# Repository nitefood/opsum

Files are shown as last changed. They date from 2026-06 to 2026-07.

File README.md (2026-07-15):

# OPSUM - The Open PSU Meter project

OPSUM is a **DC voltmeter and ammeter board** with 4mm banana socket inputs, that enables measuring and logging **voltage, current and power**, even when using a bench PSU that has no builtin telemetry feature. Communication between the board and the host happens via **UART protocol** over a dedicated USB port that is **galvanically isolated** from the PSU/DUT (*power supply unit and device under test*) side of the PCB, in order to protect the host-side (PC) from potentially destructive shorts or spikes happening on the DUT side.

This repository is structured as a **monorepo**: hardware design files, enclosure CAD files, firmware, host-side GUI tools, release binaries, communication protocol documentation, and third-party GUIs are kept together so you can build, flash, and evolve the project starting from a single source of truth.

## Features

#### Current

- **Real-time voltage, current, and power monitoring** based on the [INA226](https://www.ti.com/product/INA226) monitor IC and the [ESP32-S3](https://www.espressif.com/en/products/socs/esp32-s3) SoC.
- [Kelvin-sensed](https://en.wikipedia.org/wiki/Four-terminal_sensing) shunt layout and full noise filtering (as per TI's [datasheet](https://www.ti.com/lit/ds/symlink/ina226.pdf), chapter *6.4.2 "Filtering and Input Considerations"*) for improved measurement accuracy.
- **Reverse-polarity**, **overvoltage**, and **negative-voltage** protection circuitry.
- PMOS input protection stage with zener-clamped gate drive.
- TVS + Schottky protected INA VBUS input.
- **Galvanic isolation** protecting the host-side USB port from the PSU/DUT side.
- Handles up to **36 V** bus voltage and **20 A** current.
- Compact, low-cost, fully **open source hardware, firmware and software** project.

#### Planned

- I<sup>2</sup>C display showing real time telemetry from the board *(I<sup>2</sup>C pin header for the display is already present on the PCB, only needs designing the enclosure lid opening and in-firmware support)*

## Images
Enclosure render (outside) | Enclosure render (inside)
| - | - |
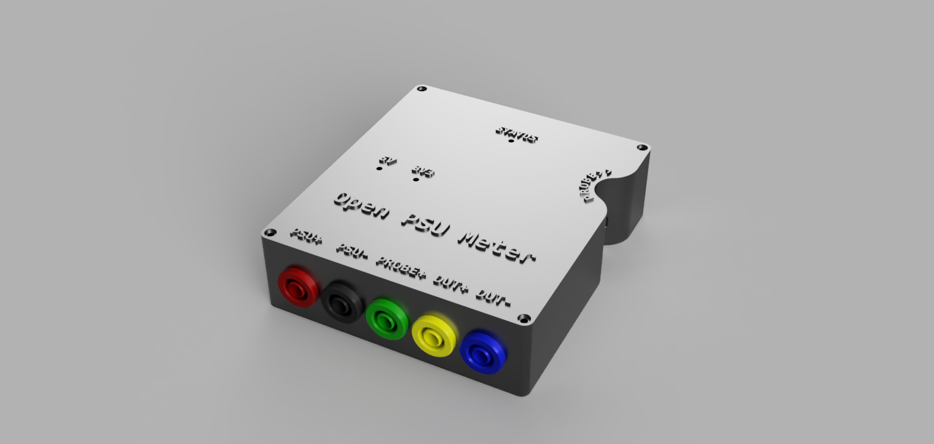
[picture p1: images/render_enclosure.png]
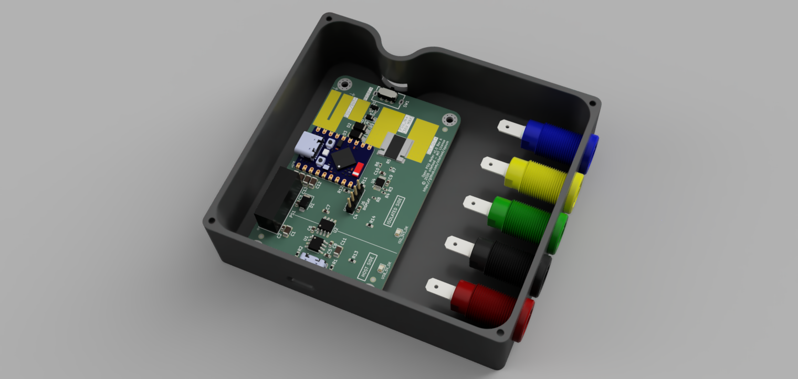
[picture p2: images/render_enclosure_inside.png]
|  |  |

PCB Layout | PCB 3D View
| - | - |
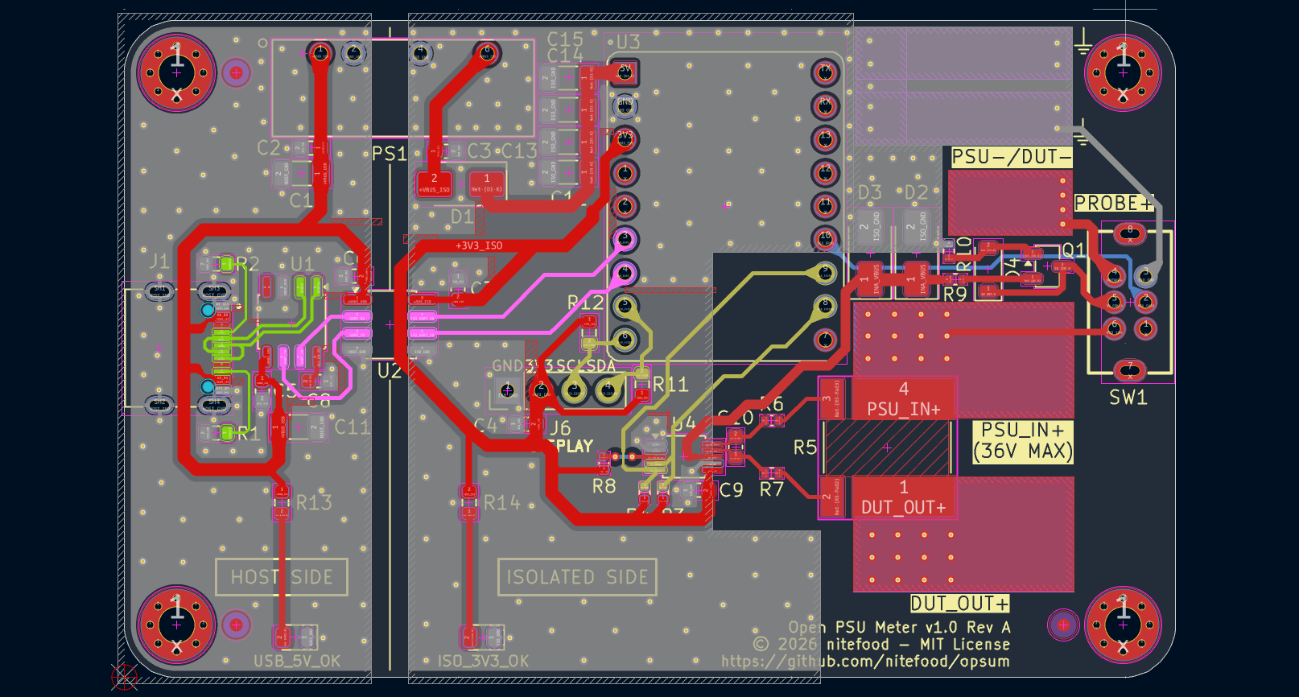
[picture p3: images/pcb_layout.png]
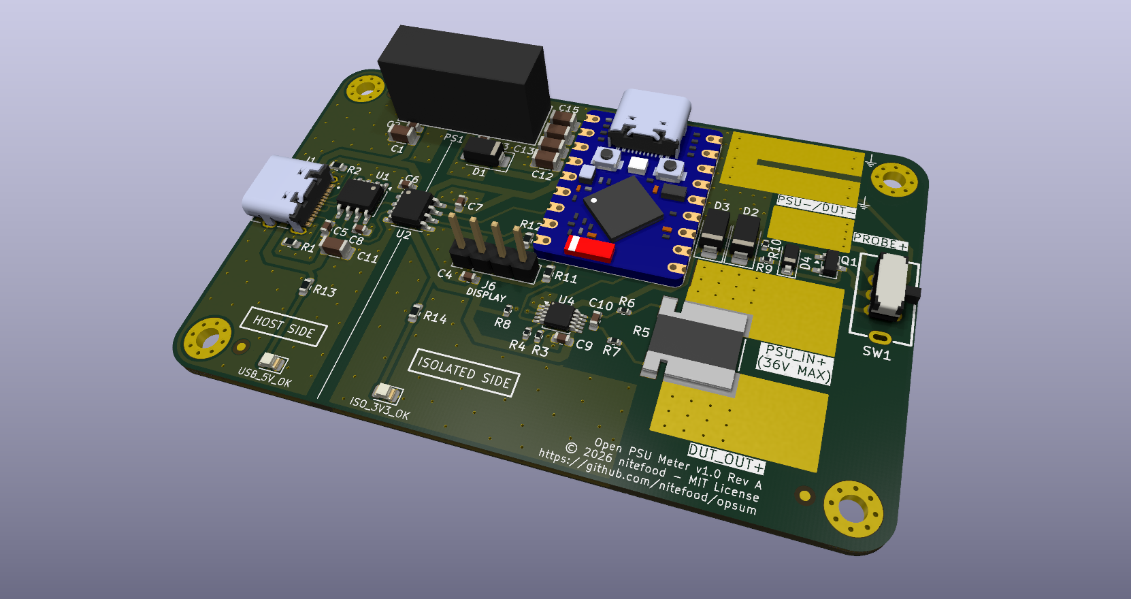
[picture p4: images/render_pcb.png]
 |  |

3D printed enclosure (top view) | 3D printed enclosure (sockets visible)
| - | - |
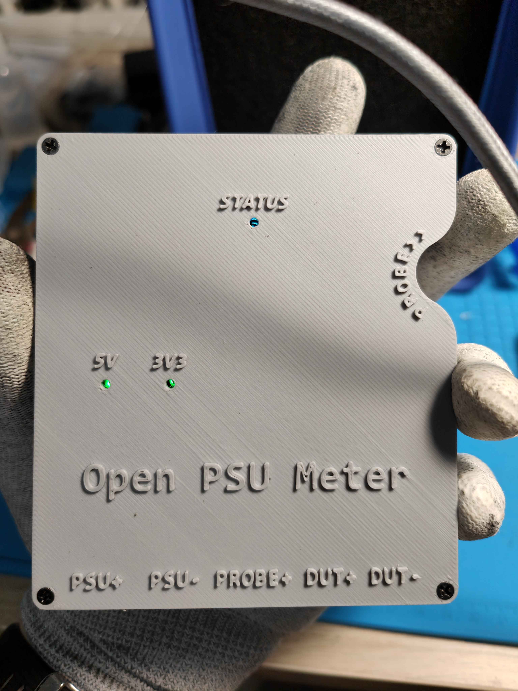
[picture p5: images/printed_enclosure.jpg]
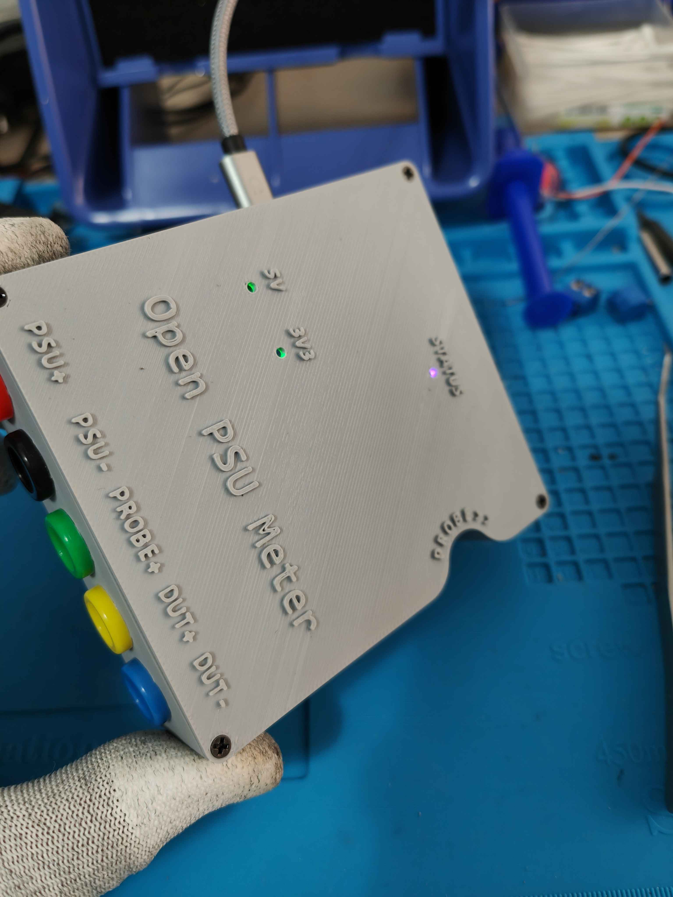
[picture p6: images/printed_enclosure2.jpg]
|  |  |

#### 3D printed enclosure (internal 12AWG wiring)
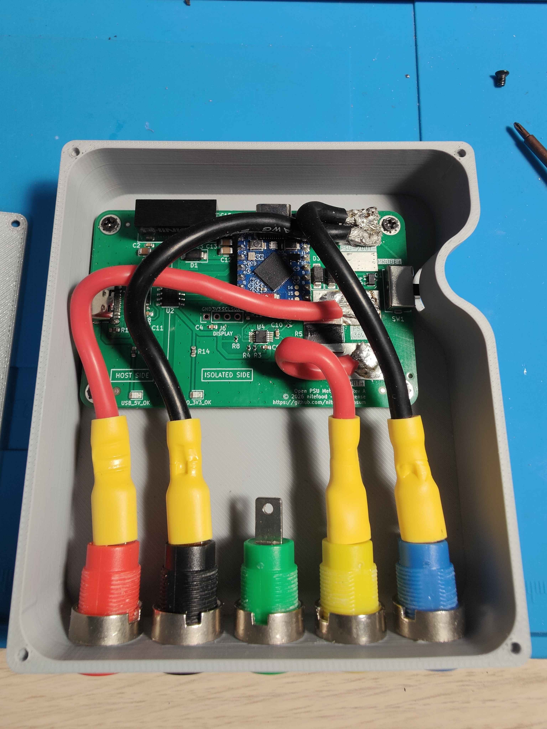
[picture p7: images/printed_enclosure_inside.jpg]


#### [Farmtech's PSU monitor](/third_party_tools/farmtech/) displaying telemetry coming from a live OPSUM board
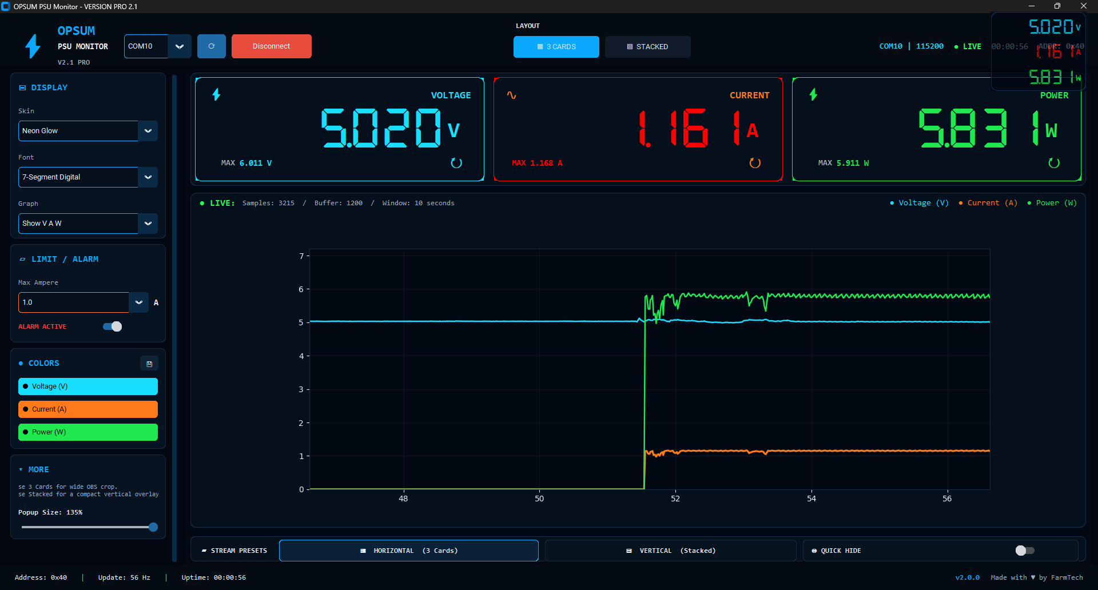
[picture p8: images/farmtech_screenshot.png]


---

## Quick Start

If you want to build the project yourself, the step-by-step approach is:

1. **Manufacture the board** using a third party PCB fab house (I've used [JLCPCB](https://jlcpcb.com/?from=DUYEWB) with great results, so tolerances and specs are guaranteed to comply with their capabilities, but any fab house should be easily capable to manufacture this board). **Gerbers, BOM and CPL** files alongside required production settings and instructions for PCB manufacturing and assembly are all in the [hardware](/hardware/) section.
	> Disclaimer: the JLCPCB link above is a referral URL, I get a little kickback if you use it to subscribe or buy from them. Thanks for your support!
2. **Solder the remaining through-hole components on the PCB** using the instruction under [howto-build](/howto-build/). I've included a bill of material for THT and hand-assembly components required to complete the project, complete with links to AliExpress to source them.
3. **First-flash the new ESP32-S3 board** with the `-FULL` image (using `esptool`). Prebuilt binaries and usage instructions for `esptool` are in the [dist](dist/) section.
4. **3D print the enclosure and assemble the finished product**. Instructions are under [enclosure](/enclosure/).
5. **Connect the USB port to your PC and use a client-side program** to interface with the OPSUM board and receve its readings. I've included a [minimal GUI](dist/opsum_gui.exe), alongside with fully featured [third party tools](third_party_tools/) compatibile with OPSUM's core firmware [protocol](./protocol-specs/core-uart.md).

If you want to flash a different firmware, or update/reflash the core firmware in the future, there is **no need to disassemble the board** to access the native MCU USB port. Just use the **isolated USB port** with the included [flash tool](dist/flashtool.exe), and reflash the board using a `-OTA` image. OPSUM's main firmware OTA image is packaged under [dist](dist/) as well.

## Open Tooling Approach

This repository includes everything, ranging from the basic OPSUM GUI plus third-party client-side tools that support the Core firmware communication protocol, to enclosure CAD models, PCB layout design files, assembly guides and protocol specification documentation.

You are free to use whichever compatible client (or firmware) matches your needs.

## Repository Layout

| Folder | Contents |
| - | - |
| [dist/](dist/) | release binaries + compilation and flash instructions |
| [protocol-specs/](protocol-specs/) | **DFU** (flashing) and **UART** (runtime communication with the host) protocol specs |
| [src/Firmware/](src/Firmware/) | **Core** (main) and **DFU** (flash update mode) firmware source code |
| [src/GUI/](src/GUI/) | host-side GUI tools source code root folder |
| [src/GUI/flash-tool/](src/GUI/flash-tool/) | desktop DFU flashing GUI source code |
| [src/GUI/opsum-gui/](src/GUI/opsum-gui/) | minimal OPSUM runtime GUI frontend source code |
| [third_party_tools/](third_party_tools/) | bundled alternative host-side tools and board-side firmware binaries |
| [hardware/](hardware/) | schematic, PCB layout, BOM, CPL, Gerbers and manufacturing guide |
| [enclosure/](enclosure/) | CAD files for the OPSUM case |
| [howto-build/](howto-build/) | Manual assembly and soldering step-by-step instructions for the OPSUM board project |

## Contributing

**OPSUM is inteded as an open, community driven project**. Anyone is welcome to contribute to it by creating or improving client-side tools, firmware, enclosure, PCB design, protocol specs or documentation!

## Acknowledgements

This project was born out of the desire to improve my PCB design skills, and to document a complete DIY approach to getting a full featured ammeter from scratch, instead of buying one.

In this endeavor, I've received a lot of precious support and ideas from the [JFIXX](https://www.youtube.com/@JFIXX1) community. If you want to join us to say hello, his [discord](https://discord.gg/TcsUshz67p) server is a welcoming and friendly place, full of very skilled and amazing techs!

## Supporting the project

If you like this project and want to support it, you can do so by clicking the button below. Thank you! <3

"Buy Me A Coffee" (https://www.buymeacoffee.com/nitefood)

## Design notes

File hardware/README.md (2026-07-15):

# Hardware Design Files

---

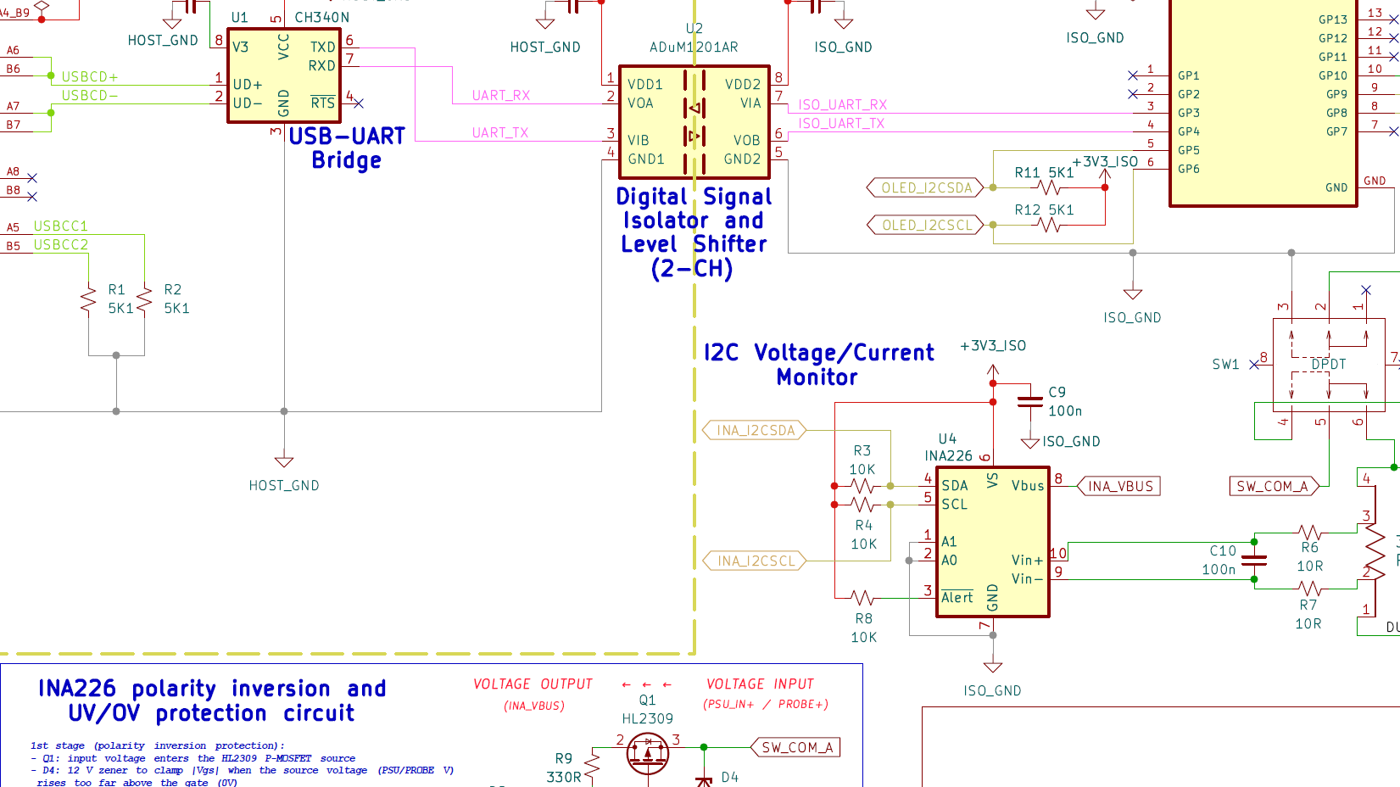
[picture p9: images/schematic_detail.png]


---

## Folder contents

This folder hosts electrical and manufacturing design assets for the OPSUM PCB.

## CAD software used

- The OPSUM PCB was designed entirely using the [KiCad v10.0](https://www.kicad.org/) EDA software.

- PCBs were manufactured using [JLCPCB](https://jlcpcb.com/?from=DUYEWB).

	> Disclaimer: the JLCPCB link above is a referral URL, I get a little kickback if you use it to subscribe or buy from them. Thanks for your support!
- Production files were generated by using the excellent [kicad-jlcpb-tools](https://github.com/bouni/kicad-jlcpcb-tools) KiCad plugin.

## Folder structure

| Folder/File name | Content |
| - | - |
| [schematic/](./schematic/) | Full board schematic in .PDF format |
| [KiCad/](./KiCad/) | KiCad project files for schematic and PCB layout |
| [jlcpcb/](./jlcpcb/) | BOM (Bill of Materials), CPL (Component Placement List), Gerber manufacturing outputs |

## Step-by-step Manufacturing Guide (for JLCPCB)

1. Login to [JLCPCB](https://jlcpcb.com/?from=DUYEWB) and click the **Get Instant Quote** button
2. Click "Add gerber file" and upload the [Gerber .zip archive](./jlcpcb/production_files/GERBER-Open_PSU_Meter_ESP32.zip)
3. Layers count and PCB size will be both autodetected from the Gerber files. You can leave all settings as they are. Optionally, you may prefer setting `Surface Finish` to *LeadFree HASL*, but the default will do just fine
4. Scroll to the bottom of the page and enable the **PCB Assembly** toggle. Keep the default values there as well
5. Ensure you pick the desired **PCBA Qty** value: this will determine how many of the manufactured PCBs will also get their SMT components assembled
6. Click Next, then Next.
7. Add the [BOM](./jlcpcb/production_files/BOM-Open_PSU_Meter_ESP32.csv) and [CPL](./jlcpcb/production_files/CPL-Open_PSU_Meter_ESP32.csv) files, then click  **Process BOM & CPL**
8. Ignore the warning (*"The below parts won't be assembled due to data missing.
U3,PS1 designators don't exist in the BOM file."*). This is intentional, since those parts (ESP32-S3-Zero breakout board and isolated DC/DC converter) are to be sourced externally and hand soldered on the PCB. Refer to the [howto-build](../howto-build/) guide for details.
9. Review the matched parts and ensure all are in stock. Click Next.
10. **Carefully check part orientation on the board**. Sometimes their automated system fails to correctly orient the components on the pads. In my case, I had to re-orient **U1** and **Q1**. Just **click the component to select it**, and **press the space key** until they're in the correct orientation (the purple dot should align with the white silkscreen dot/arrow). They should look like this:

	| U1 | Q1 |
	| - | - |
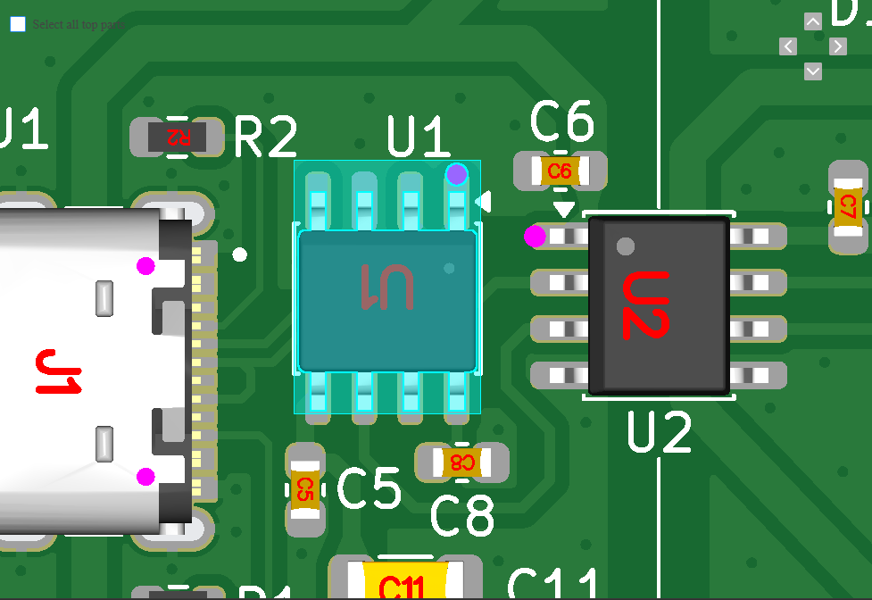
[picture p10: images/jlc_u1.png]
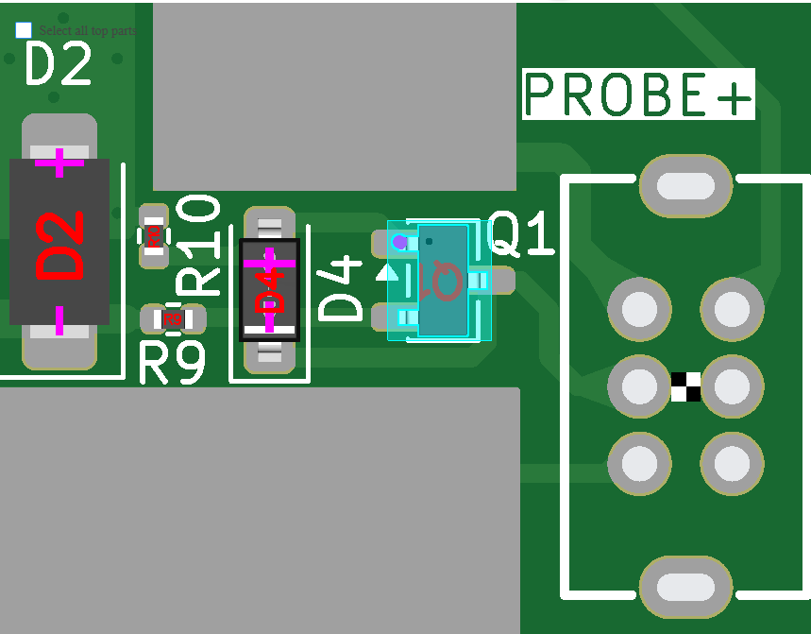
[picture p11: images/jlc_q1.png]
	|  |  |
11. Click Next and pick "*Research/Education/DIY/Entertainment*" -> "*DIY Hobby Circuit Board - HS Code 902300*" from the product description dropdown, then click **Save to Cart**
12. Select the cart item (PCB Manufacture + PCBA) and proceed to Secure Checkout. You will be able to pick a shipping method, enter your shipping address, and complete the order.

## Hand Soldering Guide for through hole components

Once the board is manufactured and the enclosure is printed, refer to the [How To Build](../howto-build/) section to finish assembling the tool.

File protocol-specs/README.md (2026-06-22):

# Protocol Specs

Technical-reference-only folder.

This folder contains protocol documentation intended for implementers writing host/client code that communicates with OPSUM firmware.

Contents:

- [dfu-uart.md](dfu-uart.md): DFU transport, framing, commands, and update flow.
- [core-uart.md](core-uart.md): runtime UART commands and telemetry frame format.

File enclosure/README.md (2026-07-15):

# Enclosure Design Files

## CAD software used

- The OPSUM enclosure was designed entirely using [Autodesk Fusion](https://www.autodesk.com/products/fusion-360/personal).

## Folder contents

This folder hosts the OPSUM enclosure STEP file (in its latest revision).

## 3D Print settings

> Note: these are the settings I used on my `Elegoo Centauri Carbon 2` 3D printer, with the standard nozzle. They should work fine for any other printer.

The enclosure can be printed with standard settings, in **PLA** or **PETG** material:
- Layer height: 0.2mm
- Infill: 15% (minimum)
- optionally use an external brim to improve first layer adhesion

## Assembly Guide

Refer to the [How To Build](../howto-build/) section for a detailed step-by-step assembly guide for the OPSUM board.

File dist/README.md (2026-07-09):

# Project Binaries

This folder contains prebuilt firmware binaries for self-flashing OPSUM boards.

Current files:

- `firmware-s3-FULL.bin`
- `firmware-s3-OTA.bin`

## What Each Binary Is For

- `firmware-s3-FULL.bin`:

  **Use for first time flashing of a new/blank board. This firmware installs DFU mode and the main firmware on the board**:
  1. Install [esptool](https://docs.espressif.com/projects/esptool/en/latest/esp32/installation.html#how-to-install)
  2. Put the board in bootloader mode: keep the "boot" button pressed while connecting the USB-C cable to your PC
  3. Erase the current flash contents: `esptool erase-flash`
  3. Flash the firmware to the board: `esptool write-flash 0x0 firmware-s3-FULL.bin` 

- `firmware-s3-OTA.bin`:

  **Use to reflash, update or change the main firmware on an OPSUM board**:
  - This is the main firmware image only. Use the included [flash tool](flashtool.exe) to set the board to DFU mode and program it.

- `flashtool.exe`:

  This is the helper tool that reboots the board into DFU mode, and allows flashing the main firmware image.

- `opsum_gui.exe`:

  Minimal host-side GUI tool that communicates with the board and displays the Volt/Amp/Watt readings on screen.

## Compiling the core firmware from source

The binaries are produced from MicroPython ESP32-S3 port with the project manifest.

Example (bash):

```bash
MICROPYTHON_PORT_DIR="/path/to/micropython/ports/esp32"
REPO_ROOT="/path/to/opsum"

cd "$MICROPYTHON_PORT_DIR"
make BOARD=ESP32_GENERIC_S3 FROZEN_MANIFEST="$REPO_ROOT/src/Firmware/Core/manifest.py"

cp build-ESP32_GENERIC_S3/micropython.bin "$REPO_ROOT/dist/firmware-s3-OTA.bin"
```

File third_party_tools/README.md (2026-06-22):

# Third-Party Tools

This folder contains **third party GUI tools** that can be used as alternatives to the bundled [OPSUM GUI tool](../src/GUI/opsum-gui/), since they support the Core firmware [UART communication protocol](../protocol-specs/dfu-uart.md).

Subfolders are organized by tool author name.

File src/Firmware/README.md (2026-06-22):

# Firmware Overview

This folder contains all firmware (board-side) components.

Communication Protocol references:

- [DFU Mode Communication Protocol](../../protocol-specs/dfu-uart.md)
- [Core Firmware Communication Protocol](../../protocol-specs/core-uart.md)

## Subfolders

- [Core](Core/): runtime application firmware (*written in MicroPython*).
- [DFU](DFU/): UART-based DFU updater firmware (*written in C using the ESP-IDF framework*).

## Typical Workflow

1. Program DFU firmware on a board during initial setup.
2. Program runtime firmware (`Core`) as initial app image.
3. For future updates, use the [flash tool](../GUI/flash-tool/) to push new app images over DFU.

This flow is designed so you can build and maintain your own board without vendor-locked tooling.

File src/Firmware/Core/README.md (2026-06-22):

# Core Firmware (Runtime App)

This folder contains the main runtime firmware logic.

Main entry file:

- `main.py`

Protocol reference:

- [core-uart.md](../../../protocol-specs/core-uart.md)

## Runtime UART Commands

Current control commands handled by runtime firmware:

- `STATUS`
  - replies with the current firmware and board hardware info to the host
  - Response format:
    - `OK_RUNNING,{FIRMWARE_NAME},{VERSION},{TARGET_BOARD_REV},{BOARD}`

- `ENTERDFU`
  - Sets boot target to DFU app partition and reboots.

- `STOP`
  - Stops the main firmware loop (useful for stopping the firmware loop and breaking into the MicroPython REPL while debugging live firmware changes).

## Purpose

The runtime app provides board functionality and telemetry streaming. It can hand off control to DFU mode for firmware updates.

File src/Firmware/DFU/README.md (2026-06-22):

# OPSUM DFU

This directory contains a minimal (~256Kb) native ESP-IDF DFU updater written in C and built with PlatformIO.

> If you only need to program and use boards (not modify DFU firmware), follow the instructions under [/dist](../../../dist/).

## Board Target

- PlatformIO environment: `esp32s3_generic_n4r2`
- Actual board definition in use: `esp32-s3-devkitc-1` (generic ESP32-S3)
- Expected memory profile: 4 MB flash + 2 MB PSRAM (for boards like ESP32-S3-Zero N4R2 variants)

## DFU Firmware Overview

- Dedicated DFU app running from partition `dfu` (`ota_0`)
- Updates only partition `app` (`ota_1`)
- Erases partition `storage` (1 MB LittleFS area) only after successful image verification
- UART DFU protocol only on `TX=GPIO3`, `RX=GPIO4`
- Built-in NeoPixel status indication on `GPIO21`: solid yellow in IDLE/READY, fast yellow blink during active transfer
- Integrity verification uses CRC32.

## Protocol Details

- DFU UART protocol: [/protocol-specs/dfu-uart.md](../../../protocol-specs/dfu-uart.md)
- Core runtime UART protocol (for mode detection and runtime control): [/protocol-specs/core-uart.md](../../../protocol-specs/core-uart.md)

## Build

From this folder:

```powershell
pio run -e esp32s3_generic_n4r2
```

## Flash DFU app

```powershell
pio run -e esp32s3_generic_n4r2 -t upload
```

## Flash Layout and Partition Setup

This section describes how to prepare the board flash layout so the DFU updater can manage a dedicated main application partition plus mandatory 1 MB storage partition.

### 1. Partition map

Used file: `partitions_dfu.csv`

| Name | Type/Subtype | Offset | Size | Purpose |
|---|---|---:|---:|---|
| nvs | data/nvs | 0x9000 | 0x6000 (24 KB) | key-value config |
| otadata | data/ota | 0xF000 | 0x2000 (8 KB) | OTA boot metadata |
| phy_init | data/phy | 0x11000 | 0x1000 (4 KB) | PHY init |
| dfu | app/ota_0 | 0x20000 | 0x40000 (256 KB) | DFU updater app |
| app | app/ota_1 | 0x60000 | 0x2A0000 (2.625 MB) | main firmware slot |
| storage | data/littlefs (0x83) | 0x300000 | 0x100000 (1 MB) | 1MB LittleFS storage |

### 2. Prerequisites

- Python + PlatformIO CLI installed
- USB serial access to the ESP32-S3 board
- Board in ROM download mode for first flash (manual boot/reset procedure as required by board)

From repository root:

```powershell
Set-Location "src/Firmware/DFU"
```

### 3. Build the DFU project

```powershell
pio run -e esp32s3_generic_n4r2
```

This produces:

- bootloader binary
- partition table binary
- DFU app binary

### 4. Initial full flash (recommended)

Option A (simplest):

```powershell
pio run -e esp32s3_generic_n4r2 -t upload
```

This flashes bootloader + partition table + DFU app with the configured partition CSV.

### 5. Manual explicit flashing (if you want full control)

1. Identify serial port (example `COM7`).
2. Use files generated under `.pio/build/esp32s3_generic_n4r2/`.

Example (adjust `COMx`):

```powershell
esptool --chip esp32s3 --port COM7 --baud 921600 erase_flash
esptool --chip esp32s3 --port COM7 --baud 921600 write_flash -z `
	0x0000 .pio/build/esp32s3_generic_n4r2/bootloader.bin `
	0x8000 .pio/build/esp32s3_generic_n4r2/partitions.bin `
	0x20000 .pio/build/esp32s3_generic_n4r2/firmware.bin
```

Notes:

- `firmware.bin` here is the DFU updater image and is placed at `dfu` (`ota_0`) offset `0x20000`.
- `otadata` is created and managed by ESP-IDF OTA APIs during runtime.

### 6. Verify flash layout on device

After flashing and reset, connect monitor:

```powershell
pio device monitor -b 115200
```

>Note: `pio device monitor -b 115200` only opens the serial terminal; it does not force DFU mode by itself. Press reset (or power-cycle) to observe DFU boot logs and LED status.

The DFU app should boot and expose the DFU UART protocol on GPIO3/GPIO4.
In DFU firmware, the NeoPixel on GPIO21 is:

- Solid yellow in `IDLE/READY`
- Fast yellow blink during active transfer (`RECEIVING/VERIFYING`)

The DFU app also prints a startup line and a periodic heartbeat (`DFU alive: ...`) every 5 seconds at warning level.

### 7. DFU path validation sequence

Steps to validate the DFU firmware and protocol path end-to-end:

1. Flash DFU image using this layout.
2. Use host DFU protocol to program main app image into `app` (`ota_1`).
3. On successful `END`, DFU erases `storage` and sets boot target to `app`.
4. Reboot to run main firmware.

### 8. Maintenance commands

Rebuild DFU:

```powershell
pio run -e esp32s3_generic_n4r2
```

Reflash DFU only:

```powershell
pio run -e esp32s3_generic_n4r2 -t upload
```

If you need a clean re-provision:

```powershell
esptool --chip esp32s3 --port COM7 erase_flash
```

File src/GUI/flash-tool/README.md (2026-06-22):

# OPSUM DFU Flash Tool

This folder contains the source code for the desktop GUI flasher for the dedicated OPSUM _Device Firmware Update_ (**DFU**) partition.

> The DFU communication protocol is documented [here](../../../protocol-specs/dfu-uart.md)

## Supported Features

- UART connection to the board.
- DFU-mode detection via binary `HELLO` / `HELLO_RSP` handshake.
- Automatic baud handling:
  - normal/runtime default: `115200`
  - DFU preferred probe speed: `921600`
  - automatic reconnect/probing during mode detection (no baud dropdown)
- Clear UI mode indication (`Disconnected`, `DFU Mode`, `Normal Mode`, `Unknown`).
- APP image flashing via DFU protocol commands:
  - `HELLO`
  - `BEGIN`
  - `DATA` (sequential chunks)
  - `END`
  - `REBOOT`
- Transfer chunk size automatically uses `HELLO_RSP.max_chunk`, capped at `4096` bytes.
- Transfer progress bar and session log.
- User abort (`ABORT`) during transfer.

## Runtime Mode Detection

Normal mode is detected with cleartext UART command:

- Host sends: `STATUS\r\n`
- Firmware responds: `\r\nOK_RUNNING,{FIRMWARE_STRING}\r\n`

Where:

- `FIRMWARE_STRING = "{FIRMWARE_NAME},{VERSION},{TARGET_BOARD_REV},{BOARD}"`

The tool parses and displays:

- firmware name
- version
- target board revision
- board identifier

## Protocol Assumptions for the DFU Firmware

The tool matches the DFU implementation in `Firmware/DFU/src/main.c`:

- Framing bytes: `0x44 0x46` (`DF`)
- Protocol version: `0x01`
- Sequence numbers must match expected value in DFU target.
- CRC32 behavior matches DFU firmware implementation (`esp_rom_crc32_le` wrapper style).
- Target partition ID for flashing APP: `0x01`
- Typical max chunk from DFU target: `4096` bytes

## Run

Install Python dependencies (from the GUI requirements file):

```bash
pip install -r src/GUI/opsum-gui/requirements.txt
```

Then run the script:

```bash
python src/GUI/flash-tool/flashtool.pyw
```

## Basic Workflow

1. Connect isolated UART to board (`TX=GPIO3`, `RX=GPIO4` on MCU side).
2. Open the tool.
3. Select serial port.
4. Click `Connect`.
5. Mode detection starts automatically.
   - Tool probes DFU automatically at configured probe bauds.
   - If no DFU response is found, tool falls back to normal/runtime baud.
   - If DFU responds to `HELLO`, tool enters `DFU Mode`.
   - If runtime responds with `OK_RUNNING,...`, tool enters `Normal Mode` and shows firmware details.
6. Select firmware `.bin` file.
7. Click `Flash APP Partition`.
8. Wait for `END` success and `REBOOT`.

## Notes

- The DFU target enforces partition bounds and protocol checks.
- If image size exceeds APP partition size reported by `HELLO_RSP`, the tool rejects it.
- The DFU target erases `storage` (LittleFS) upon successful commit.

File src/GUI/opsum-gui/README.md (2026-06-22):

# OPSUM GUI (Runtime Frontend)

>This tool is to be considered as just an example of how to interact with the core firmware running on the board, and display its readouts on the connected host PC.

This folder contains the source code for the host-side, minimal OPSUM runtime GUI frontend. 

## Run

Install Python dependencies:

```bash
pip install -r src/GUI/opsum-gui/requirements.txt
```

Then run the GUI:

```bash
python src/GUI/opsum-gui/opsum_gui.pyw
```

## Notes

- This GUI is intended for runtime monitoring and interaction.
For firmware updates, the dedicated [DFU flash tool](../flash-tool/) source code is also included.

- The OPSUM protocol is open by design, so [third-party client tools](../../../third_party_tools/) in this repository can be used in place of this.

- Further tools can be freely developed as well, as long as they follow the core [UART communication protocol](../../../protocol-specs/core-uart.md) to talk to the OPSUM board's firmware.

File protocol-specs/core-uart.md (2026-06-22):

# OPSUM Core UART Protocol

Host-to-runtime protocol for command/control and runtime-to-host binary telemetry.

## Scope

- Defines command tokens accepted by runtime firmware.
- Defines binary telemetry frame format emitted by runtime firmware.
- Covers mixed text and binary traffic sharing the same UART stream.

## Transport

- UART settings: `115200`, `8N1`.
- Device-side pins by board:
  - ESP32-S3: TX=GPIO3, RX=GPIO4
  - ESP32-C3: TX=GPIO2, RX=GPIO3
- Commands are plain ASCII byte tokens.
- Telemetry is fixed-size binary framing.

## Runtime Command Channel

Runtime firmware reads raw UART bytes and searches for command tokens.

Supported tokens:

- `STATUS`
- `ENTERDFU`
- `STOP`

### Command Matching Rules

- Token detection is substring-based (`b"TOKEN" in data`), not line-based parsing.
- If multiple tokens appear in one read buffer, only the first matching branch is processed in this priority order:
  1. `STATUS`
  2. `ENTERDFU`
  3. `STOP`
- Tokens are case-sensitive.

### Command Responses

All command responses are ASCII text framed by CRLF.

#### `STATUS`

Response format:

```text
\r\nOK_RUNNING,{FIRMWARE_NAME},{VERSION},{TARGET_BOARD_REV},{BOARD}\r\n
```

#### `ENTERDFU`

Behavior:

- Looks up partition labeled `dfu`.
- Sets boot target to `dfu` partition.
- Sends success text.
- Waits briefly, then resets MCU.

Possible responses:

- Success: `\r\nOK_REBOOTING_INTO_DFU_MODE\r\n`
- Error: `\r\nERR_DFU_PARTITION_NOT_FOUND\r\n`
- Error: `\r\nERR_DFU_BOOT_TARGET_SET_FAILED\r\n`

#### `STOP`

Behavior:

- Stops the runtime main loop.

Response:

- `\r\nOK_STOPPING_MAIN_LOOP\r\n`

## Runtime Telemetry Channel

Runtime firmware emits one binary telemetry frame per loop iteration.

- Nominal loop delay: `10 ms`.
- Nominal telemetry rate: about `100 Hz`.
- Frame endianness: little-endian for all multi-byte fields.

### Frame Layout

```text
START[2] EVENT[1] SEQ[1] TS_MS[4] VBUS[4] CURRENT[4] VSHUNT[4] POWER[4] XOR[1] END[2]
```

Total frame size is exactly `27` bytes.

### Field Definitions

- `START`: constant marker `0xAA55` on the wire (`AA 55`).
- `EVENT`: event code. Currently only the *sample* event code `0x73` (ASCII letter 's') is supported.
- `SEQ`: unsigned 8-bit sequence counter (`0..255`, wraps).
- `TS_MS`: `uint32` millisecond tick counter (`time.ticks_ms()` masked to 32-bit).
- `VBUS`: `float32` bus voltage.
- `CURRENT`: `float32` current.
- `VSHUNT`: `float32` shunt voltage.
- `POWER`: `float32` power.
- `XOR`: checksum byte; XOR over payload bytes from `EVENT` through `POWER`.
- `END`: constant marker `0x66BB` on the wire (`BB 66`).

### Firmware Packing Model

```text
payload = struct.pack('<BBIffff', event, seq, ts, vbus, current, vshunt, power)
frame = start + payload + checksum + end
```

Where:

- `start = struct.pack('<H', 0x55AA)` resulting in wire bytes `AA 55`.
- `end = struct.pack('<H', 0x66BB)` resulting in wire bytes `BB 66`.

## Host Parsing Requirements

- Continuously scan stream for `AA 55` start marker.
- Once aligned, read fixed-length `27` bytes.
- Validate end marker and XOR checksum before accepting the sample.
- If validation fails, advance by one byte and resynchronize.
- Treat telemetry and text responses as the same physical UART stream.

## Stream Multiplexing Behavior

Binary telemetry and text command responses share one UART link.

- While runtime is streaming telemetry, command responses may appear between frames.
- Host implementations should run a framing parser for telemetry and a side text extractor for CRLF-delimited responses.

## Runtime Exit Behavior

When main loop stops (for example after `STOP`), firmware performs cleanup and may stop binary telemetry.

## Canonical Source

Reference implementation: [../src/Firmware/Core/main.py](../src/Firmware/Core/main.py)

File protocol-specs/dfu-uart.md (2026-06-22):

# OPSUM DFU UART Protocol

Host-to-device protocol used to program the main firmware image through the DFU app.

This document is the protocol specification for tool/client and firmware implementation.

## Scope

- Transport: UART on dedicated DFU pins only (device TX=GPIO3, RX=GPIO4).
- Purpose: write and activate the main app partition.
- Integrity model: CRC32 (frame + full-image).
- Authentication/signatures, resume, and DFU self-update are not part of this protocol.

## Frame Format

All multi-byte integer fields are little-endian.

```text
SYNC[2] VER[1] CMD[1] SEQ[2] LEN[2] PAYLOAD[LEN] CRC32[4]
```

- `SYNC`: fixed `0x44 0x46` (`DF`).
- `VER`: protocol version `0x01`.
- `SEQ`: request sequence number from host.
- `LEN`: payload length in bytes.
- `CRC32`: computed over `VER..LEN..PAYLOAD` (sync excluded).

## Limits

- Maximum frame payload (`LEN`): `4104` bytes.
- `DATA` payload header is 8 bytes: `offset[4] + data_len[2] + reserved[2]`.
- Maximum safe `DATA.data_len`: `4096` bytes.

## Commands

| Code | Name | Dir | Purpose |
|---|---|---|---|
| `0x01` | `HELLO` | Host -> DFU | Probe DFU, read capabilities |
| `0x02` | `HELLO_RSP` | DFU -> Host | Version/chip/chunk limits |
| `0x10` | `BEGIN` | Host -> DFU | Start update session with image metadata |
| `0x11` | `BEGIN_RSP` | DFU -> Host | Accept/reject session |
| `0x20` | `DATA` | Host -> DFU | Send one image chunk |
| `0x21` | `DATA_RSP` | DFU -> Host | ACK/NACK + progress |
| `0x30` | `END` | Host -> DFU | Finalize transfer |
| `0x31` | `END_RSP` | DFU -> Host | Commit result |
| `0x40` | `STATUS` | Host -> DFU | Query state/progress/error |
| `0x41` | `STATUS_RSP` | DFU -> Host | State/progress/error reply |
| `0x50` | `ABORT` | Host -> DFU | Cancel active session |
| `0x51` | `ABORT_RSP` | DFU -> Host | Abort acknowledged |
| `0x60` | `REBOOT` | Host -> DFU | Reboot (optional target select) |
| `0x61` | `REBOOT_RSP` | DFU -> Host | Reboot command acknowledged |

## Core Payload Contracts

### `HELLO_RSP`

```c
typedef struct {
  uint8_t  proto_version;
  uint8_t  chip_id;
  uint8_t  flags;
  uint8_t  reserved;
  uint32_t dfu_fw_version;
  uint32_t max_chunk;
  uint32_t app_partition_size;
  uint32_t storage_partition_size;
} hello_rsp_t;
```

Flag behavior:

- bit0 set: storage erase after successful update is enabled.
- bits 1..7: must be `0`.

### `BEGIN`

```c
typedef struct {
  uint32_t total_size;
  uint32_t chunk_size;
  uint32_t expected_crc32;
  uint8_t  target_id;
  uint8_t  options;
  uint16_t reserved;
  uint32_t version_code;
} begin_req_t;
```

Requirements:

- `target_id` must select main app partition.
- `chunk_size <= max_chunk` from `HELLO_RSP`.
- image size must fit app partition.

### `DATA`

```c
typedef struct {
  uint32_t offset;
  uint16_t data_len;
  uint16_t reserved;
  uint8_t  data[];
} data_req_t;
```

Rules:

- First chunk offset is `0`.
- Offsets must be strictly sequential (`next == bytes_written`).
- `data_len` must match actual bytes in `data`.
- Reject overlap, gap, out-of-range, or oversize chunks.

Suggested `DATA_RSP`:

```c
typedef struct {
  uint32_t next_offset;
  uint32_t running_crc32;
  uint16_t status;
  uint16_t reserved;
} data_rsp_t;
```

### `END`

```c
typedef struct {
  uint32_t final_size;
  uint32_t final_crc32;
} end_req_t;
```

`final_size` and `final_crc32` must match the stream actually received.

### `REBOOT`

- `LEN=0`: reboot with current boot target.
- `LEN=1`: one-byte `target_id` selects next boot target before reboot.

Target IDs:

- `0x00`: DFU partition
- `0x01`: main app partition

## Successful Update Sequence

1. Host sends `HELLO`, parses capabilities.
2. Host computes full-image CRC32 and sends `BEGIN`.
3. DFU validates metadata, prepares/erases target app region.
4. Host streams ordered `DATA` chunks.
5. DFU ACKs each chunk (`DATA_RSP`) with `next_offset`.
6. Host sends `END` with final size and CRC32.
7. DFU verifies image, erases `storage`, sets boot target to app, returns `END_RSP`.
8. Host optionally sends `REBOOT`, or DFU reboots by policy.

## Status / Error Codes

| Code | Meaning |
|---|---|
| `0x0000` | OK |
| `0x0001` | Bad frame CRC |
| `0x0002` | Unsupported protocol version |
| `0x0003` | Unknown command |
| `0x0004` | Invalid state |
| `0x0005` | Invalid argument |
| `0x0006` | Oversize image |
| `0x0007` | Partition error |
| `0x0008` | Flash write error |
| `0x0009` | Final CRC mismatch |
| `0x000A` | Sequence mismatch |
| `0x000B` | Offset mismatch |
| `0x000C` | Timeout |
| `0x000D` | Busy |
| `0x000E` | Unsupported target |
| `0x000F` | Image validation failed |
| `0x0010` | Abort completed |

## DFU State Model

Common states exposed by `STATUS_RSP`:

- `IDLE`
- `READY`
- `RECEIVING`
- `VERIFYING`
- `COMMITTED`
- `ERROR`

## Host Requirements

- Increment `SEQ` for each request.
- Always obey `HELLO_RSP.max_chunk`.
- Keep chunk offsets strictly monotonic and contiguous.
- Treat non-OK status as NACK; either retry safely or `ABORT`.
- After reconnect or session loss, restart from `HELLO`.

## Device Behavior Guarantees

- Writes only to the allowed app target partition.
- Enforces partition bounds on every write.
- On successful `END`: verifies image, erases `storage`, switches boot target to app.
- `ABORT` clears in-memory session state.
- Session timeout in `RECEIVING` returns to `IDLE`.

## Interop Note

Normal runtime UART protocol and DFU UART protocol are separate modes.

- Application mode can expose a trigger token (for example `DFU`) to reboot into DFU app.
- Once DFU app is running, UART traffic is DFU binary framing only.

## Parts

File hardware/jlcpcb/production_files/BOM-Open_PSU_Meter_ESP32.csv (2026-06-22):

Comment | Designator | Footprint | LCSC | Quantity
100K | R10 | R_0402_1005Metric | C25741 | 1
100n | C10,C2,C3,C4,C5,C6,C7,C8,C9 | C_0603_1608Metric | C14663 | 9
10K | R3,R4,R8 | R_0402_1005Metric | C25744 | 3
10R | R6,R7 | R_0402_1005Metric | C517445 | 2
10u | C1,C11 | C_1206_3216Metric | C13585 | 2
2K2 | R13,R14 | R_0603_1608Metric | C4190 | 2
330R | R9 | R_0402_1005Metric | C25104 | 1
3mR | R5 | WSL3637_VIS | C844085 | 1
47u | C12,C13,C14,C15 | C_1206_3216Metric | C96123 | 4
5K1 | R1,R11,R12,R2 | R_0603_1608Metric | C23186 | 4
ADuM1201AR | U2 | SOIC-8_3.9x4.9mm_P1.27mm | C9669 | 1
CH340N | U1 | JEITA_SOIC-8_3.9x4.9mm_P1.27mm | C2977777 | 1
DPDT | SW1 | SW-TH_SK22D02G5 | C22435631 | 1
GREEN | LED1,LED2 | LED_0805_2012Metric | C2297 | 2
HL2309 | Q1 | SOT-23-3 | C28646263 | 1
INA226 | U4 | TSSOP-10_3x3mm_P0.5mm | C49851 | 1
KH-TYPE-C-16P | J1 | KINGHELM_KH-TYPE-C-16P | C709357 | 1
MMSZ5242B | D4 | D_SOD-123 | C19077426 | 1
SMAJ36A | D2 | D_SMA | C19077550 | 1
SS14 | D1,D3 | D_SMA | C2480 | 2

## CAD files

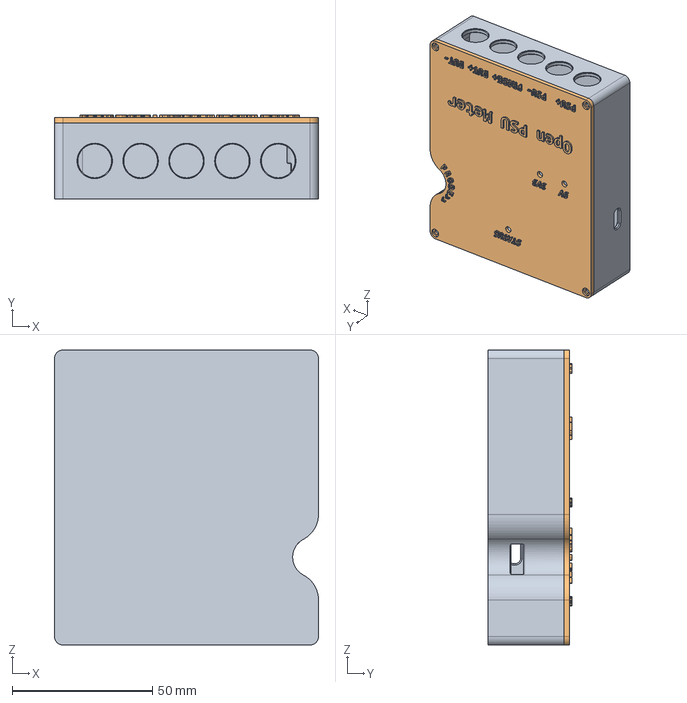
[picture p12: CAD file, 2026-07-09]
enclosure/OPSUM_Enclosure_v1.1.step
94.0 x 29.8 x 105.0 mm

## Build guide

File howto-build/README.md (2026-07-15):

# Assembling the OPSUM board (step-by-step visual guide)

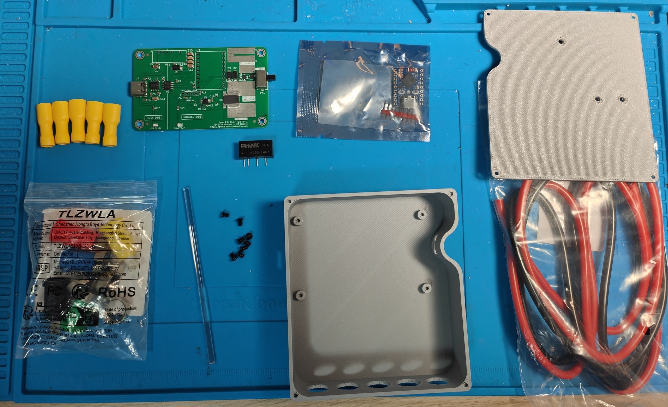
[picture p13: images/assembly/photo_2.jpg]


## Materials required

The following components are required (unless tagged "optional") to assemble the finished board.

Following is a BOM with relevant AliExpress links to source them:

| Item | Source / specification | Quantity to order | Optional |
| --- | --- | ---: | :---: |
| ESP32-S3-Zero MCU breakout board | [Link](https://aliexpress.com/item/1005009890203011.html), color: `S3-Zero` | 1 | No |
| 5V-5V 2W isolated DC/DC Converter | [Link](https://aliexpress.com/item/1005007625149966.html), color: `B0505S-2WR3` | 1 _(includes 5pcs)_ | No |
| Isolated 32A 4mm banana sockets | [Link](https://aliexpress.com/item/1005005352800055.html), color: `each color is 1 piece` | 1 _(includes 5pcs)_ | No |
| Female 6.3mm Faston connectors (50pcs) | [Link](https://aliexpress.com/item/1005009089161897.html), color: `F-Yellow-50PCS` | 1 _(includes 50pcs)_ | No |
| 12AWG wire 2m red/black | [Link](https://aliexpress.com/item/1005007468075329.html), color: `12AWG` | 1 _(includes 2 wires, 1m each)_ | No |
| M2.5 flat-head screws | 4 mm length | 8 | No |
| Acrylic rods | [Link](https://aliexpress.com/item/1005009389048602.html), `3 x 100 mm 10 pcs` | 1 | **Yes** |

## Before you start

Make sure you have the following tools:
- A decent soldering iron that can reach high enough temperature (~400°C)
- Solder (preferably leaded, for ease of use)
- Flux
- A crimper and a wire stripper (optional, but highly recommended)
- Isopropyl alcohol
- The OPSUM PCB and the above components
- _[OPTIONAL]_ a grinding pen or small Dremel-like rotary tool
- _[OPTIONAL]_ a PCB holder to aid with soldering

## Assembly steps

### 1. _[OPTIONAL]_ Cut the acrylic rods and fit them into the lid

The rods will be used as **led guides** for a better aesthetic look. Cut a single rod into **3** smaller rods with these specific sizes using your grinding pen:
- 2 x **20.5mm**
- 1 x **16.5mm**

Then push them into the enclosure lid holes (from the back side, as displayed in the picture) until they fit firmly. The two **longer** rods will be the _3V3_ and _5V_ led guides, and the **shorter** one will serve as the _Status_ led guide.

Optionally sand the ends of the cut rods to make them look smoother, using the rotary tool or a suitable tip of your grinding pen, or some fine grit sandpaper.

> Tip: when cutting the rods with your dremel/grinding pen, make sure you proceed at the **lowest possible speed**: acrylic melts easily with heat, and taking it slow ensures a cleaner, smoother and way more precise result (even without sanding). Try rotating the rod with your fingers while keeping the rotating blade firm and steady in your other hand.

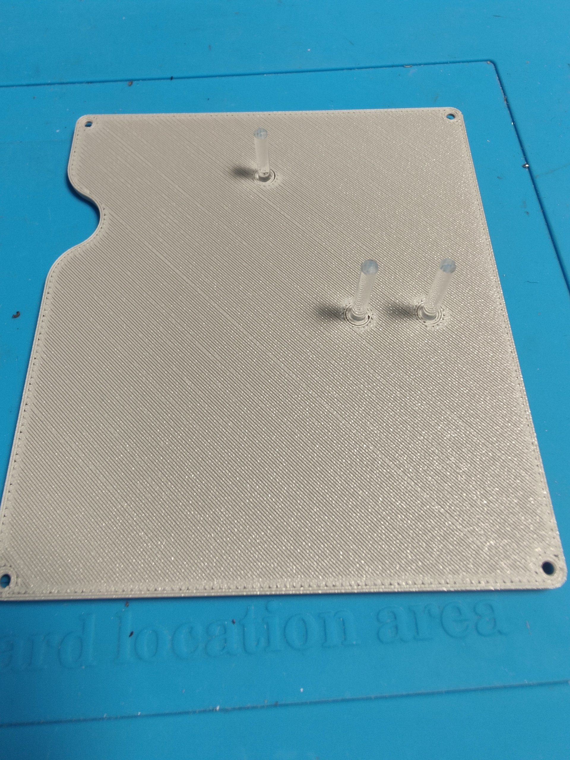
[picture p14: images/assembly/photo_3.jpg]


---

### 2. Install the banana sockets

Install the banana sockets into the enclosure base, and tighten them using the included metal rings.

**Make sure you install them one by one!**. Don't just fit them all first, you need to leave the necessary space for your fingers to tighten each ring.

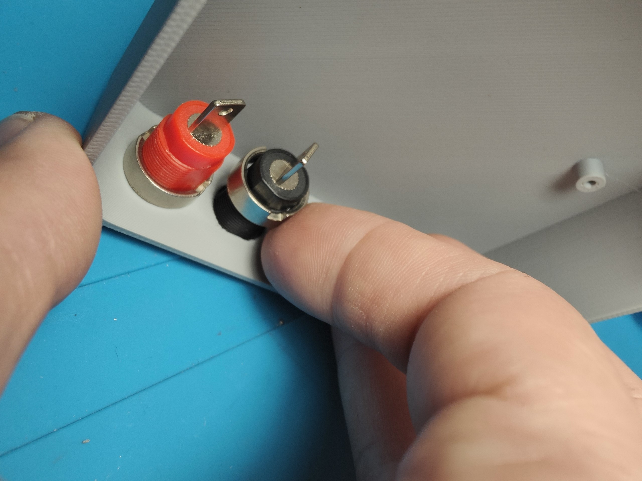
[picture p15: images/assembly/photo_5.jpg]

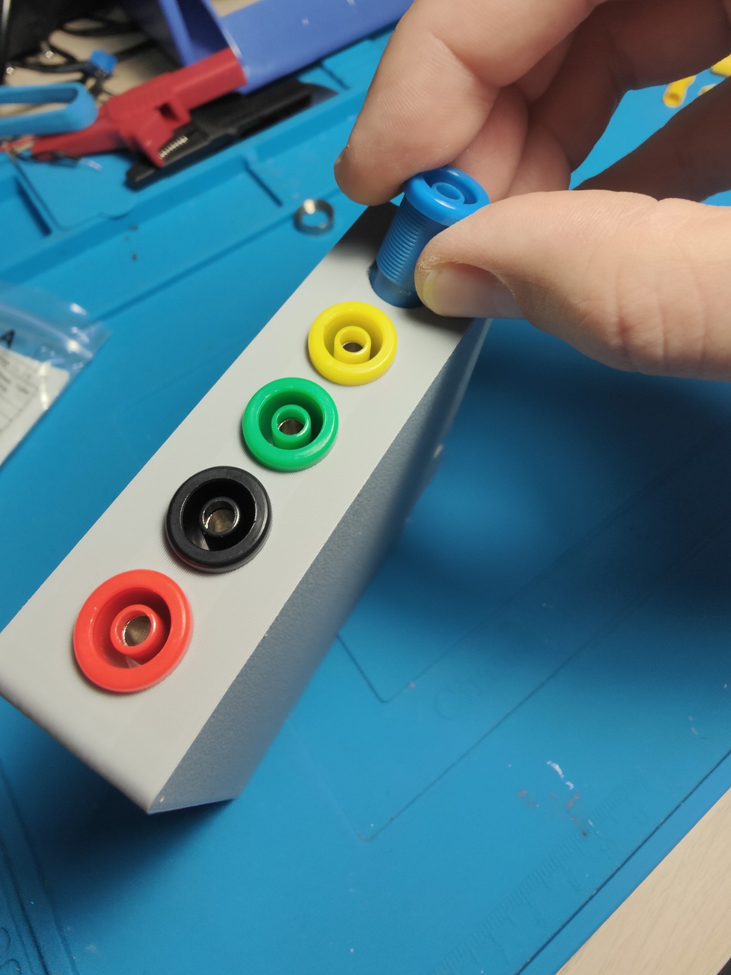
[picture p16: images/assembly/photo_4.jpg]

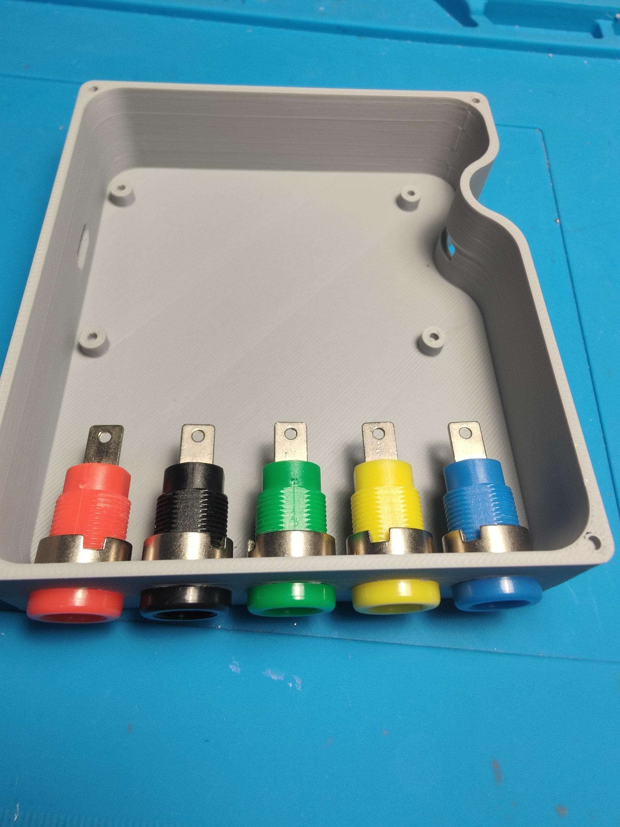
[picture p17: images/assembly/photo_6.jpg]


---

### 3. Solder the PCB pads and ESP32-S3-Zero breakout board

Tin the exposed PCB pads using **flux** and a **large soldering tip**, with a high enough (~400-420°C) temperature to comfortably melt the solder and cover as much of the pads area as possible:

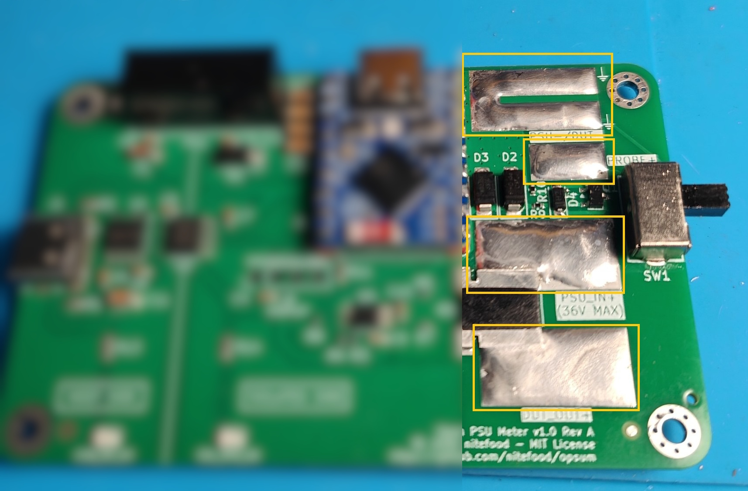
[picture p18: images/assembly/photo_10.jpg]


Then insert the pin headers in the ESP32 board as pictured below:

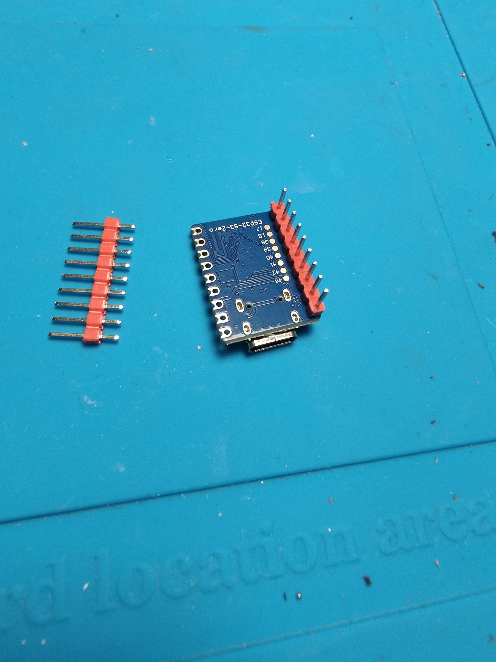
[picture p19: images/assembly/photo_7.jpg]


And place the MCU breakout board in the OPSUM PCB. **Make sure the breakout board is in the correct orientation**:
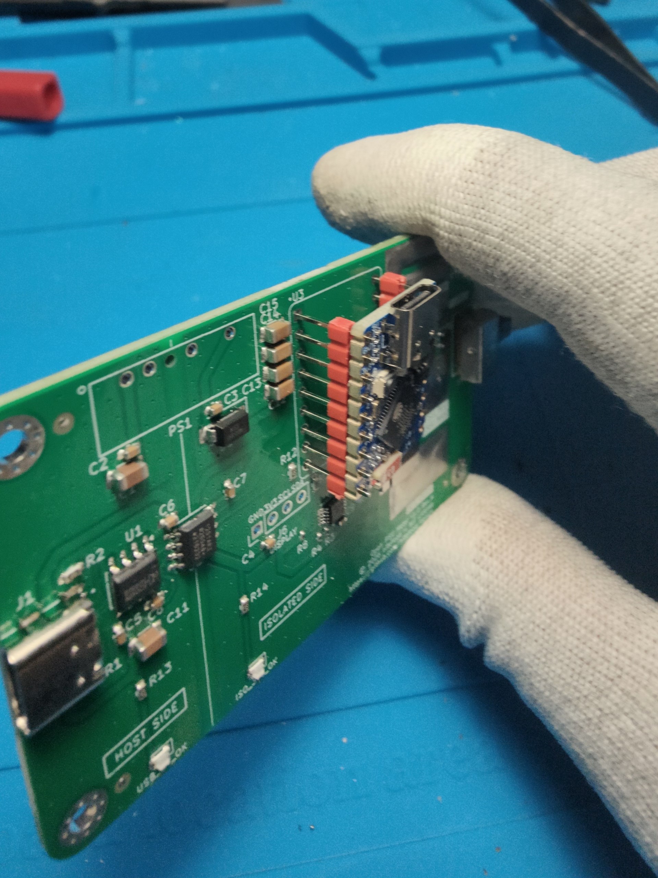
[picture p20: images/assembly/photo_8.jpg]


Then solder the each pin from the top side. Use **flux** and **a small soldering tip** with a temperature of ~300-320°C. If you have a PCB holder, use it to help keeping the PCB straight while you solder:

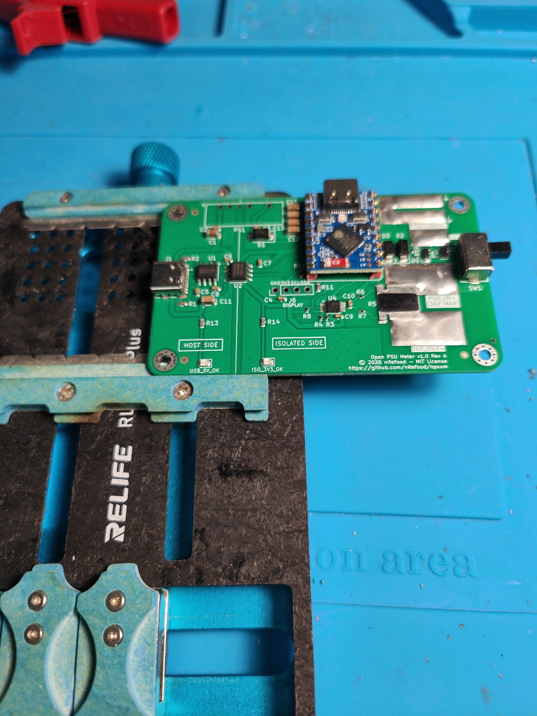
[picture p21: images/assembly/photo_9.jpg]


This is what the breakout board should look like after soldering each pin:

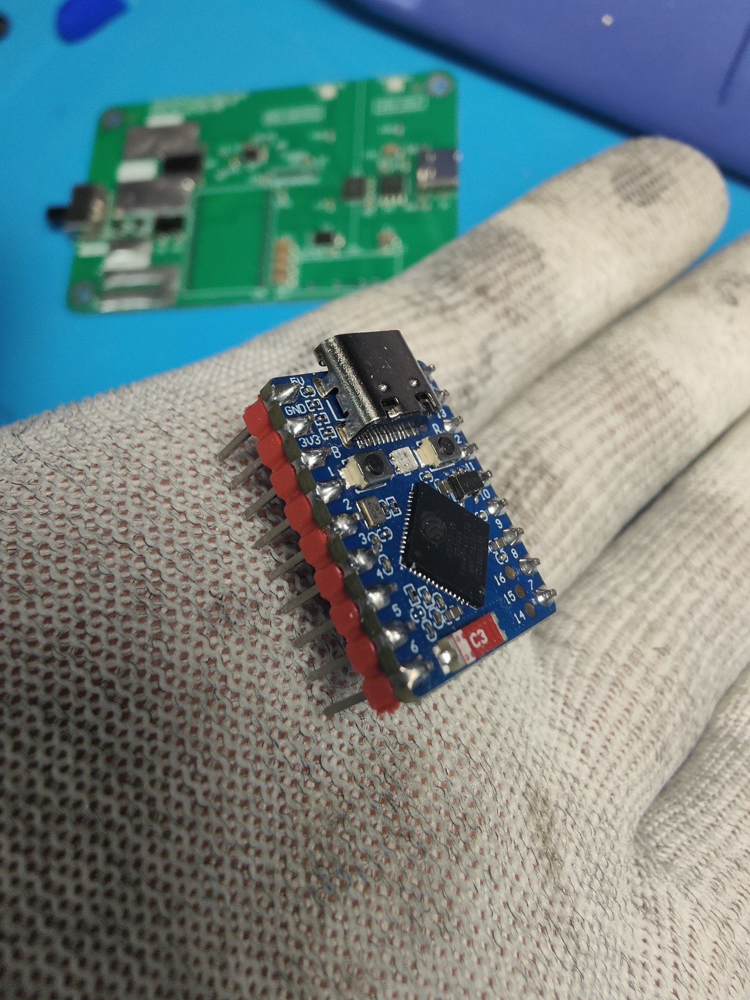
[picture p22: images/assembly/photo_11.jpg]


---

### 4. Install and solder the through hole components

Fit the breakout board whose pins you soldered before:

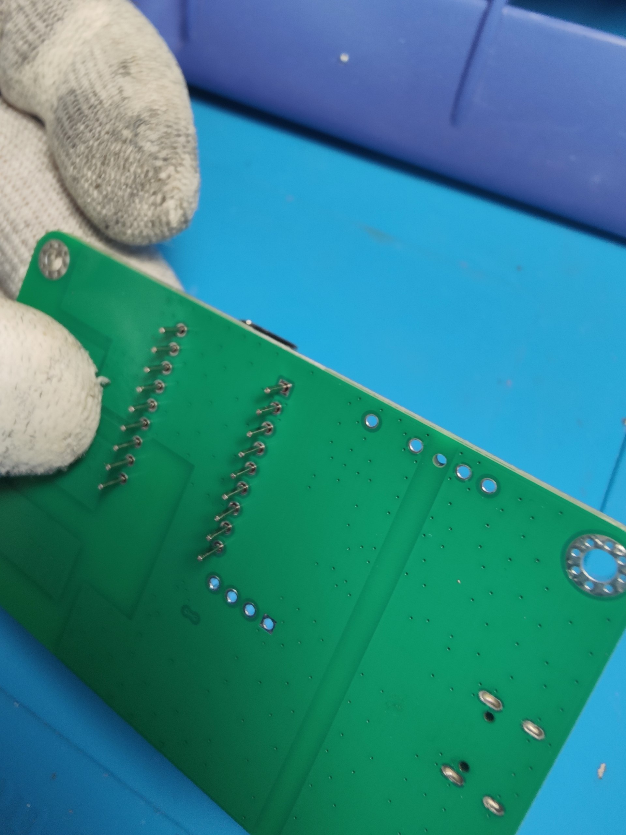
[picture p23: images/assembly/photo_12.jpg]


And the **B0505S-2WR3 isolated DC/DC converter** in the correct orientation:

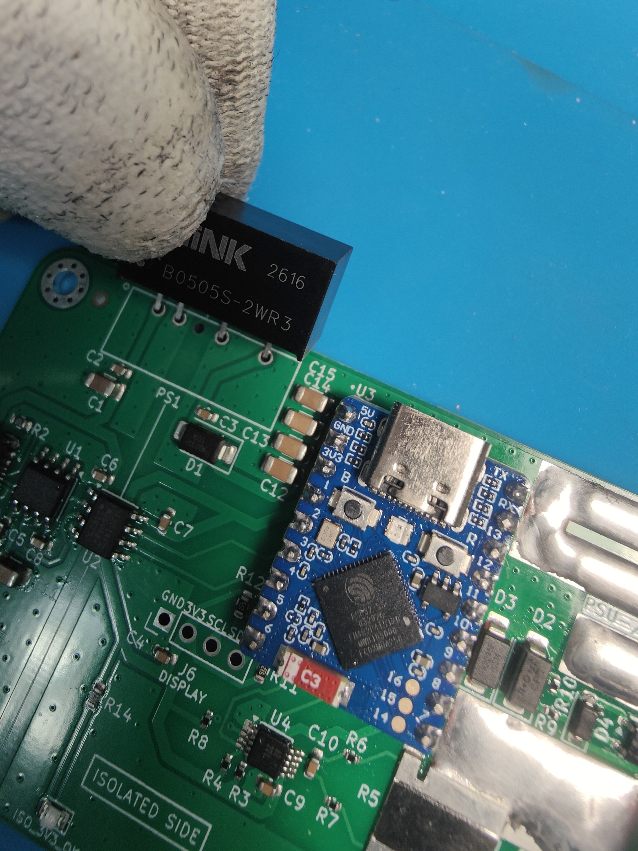
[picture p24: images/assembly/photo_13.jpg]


Then apply **flux** and use a **small soldering tip** to solder them from below:

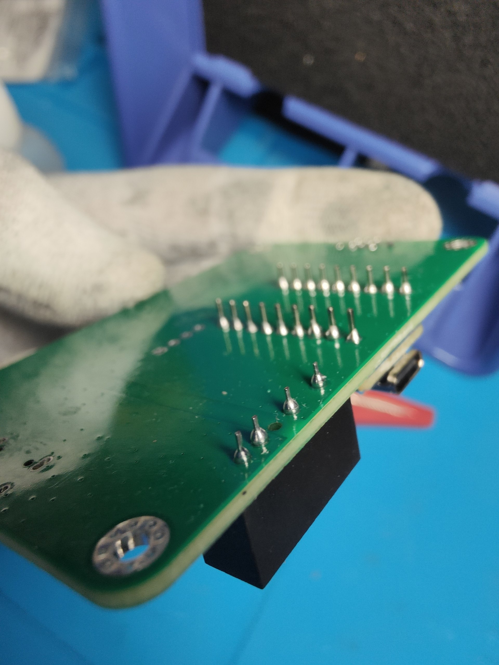
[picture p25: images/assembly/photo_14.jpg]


This is what the board should look like once every **through-hole component** and **pad** is correctly soldered:

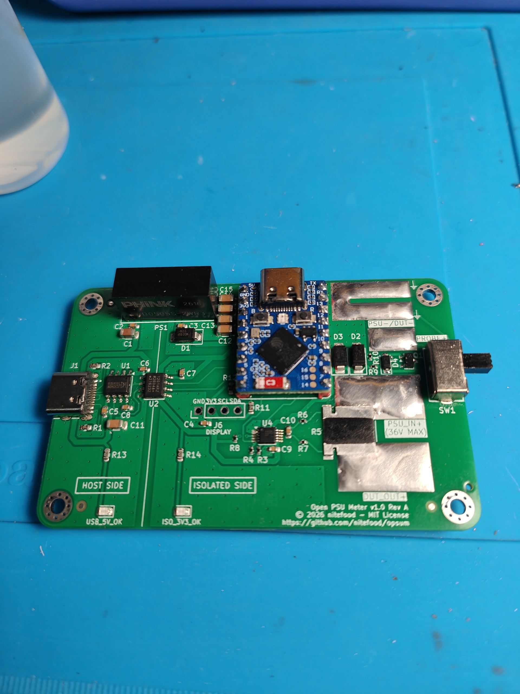
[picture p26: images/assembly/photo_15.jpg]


---

### 5. Prepare the 12AWG wires

Cut the following pieces of 12AWG wire and use this table as a reference for soldering them to the pads later:

| Pad name | Color | Wire Length
| --- | --- | --- |
| PSU+ | RED | 10.5cm |
| PSU- | BLACK | 14cm |
| PROBE+ | RED | 10.5cm |
| DUT+ | RED | 7cm |
| DUT- | BLACK | 12cm |

---

### 6. Strip, crimp and solder the wires

First of all, strip each end of the wire, exposing ~1cm of copper on each side:

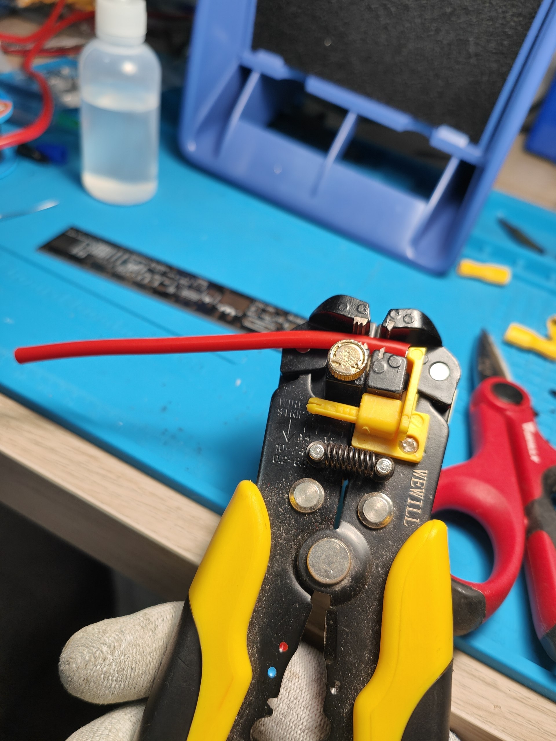
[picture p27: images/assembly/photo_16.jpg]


Then crimp a female faston connector on **only one** side of the wire:

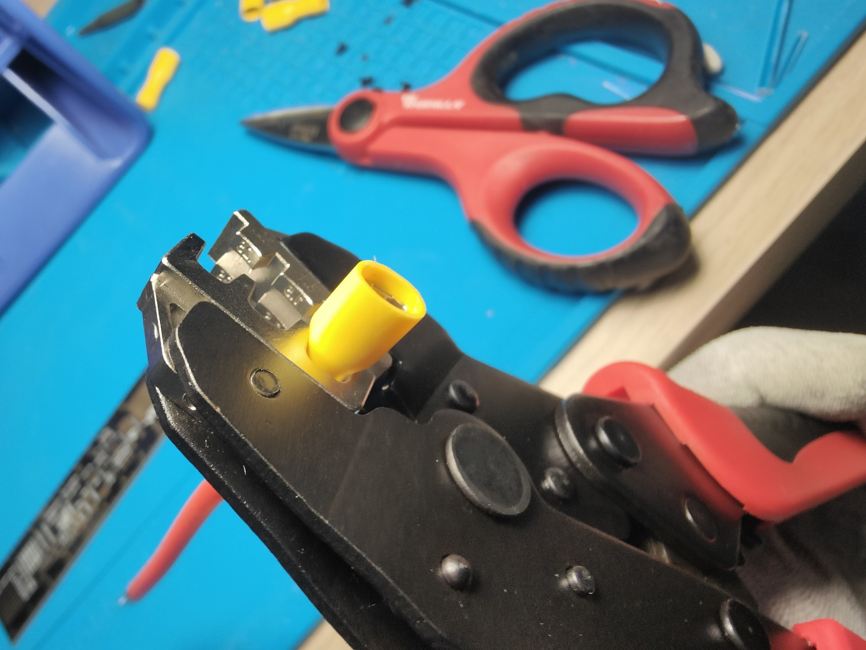
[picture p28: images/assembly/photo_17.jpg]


And apply solder to the other end. Use **flux** and a **large soldering tip** to help with the job (12AWG wire is very thick, so it may take a moment to fully wet the copper):

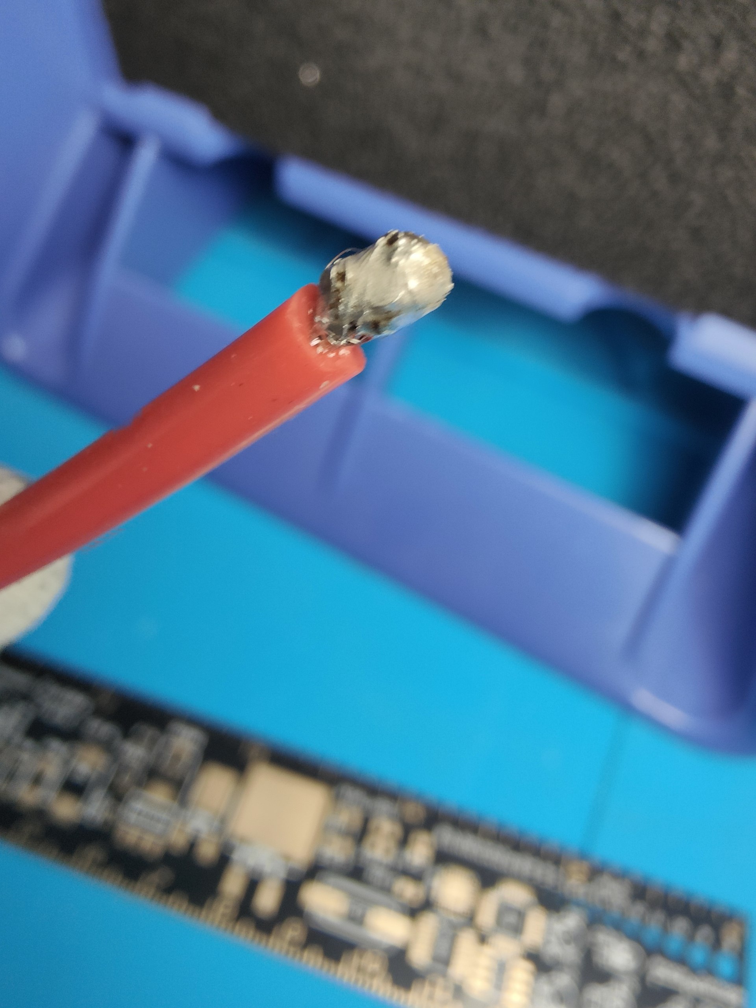
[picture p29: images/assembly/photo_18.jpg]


This is what the wire should look like in the end:

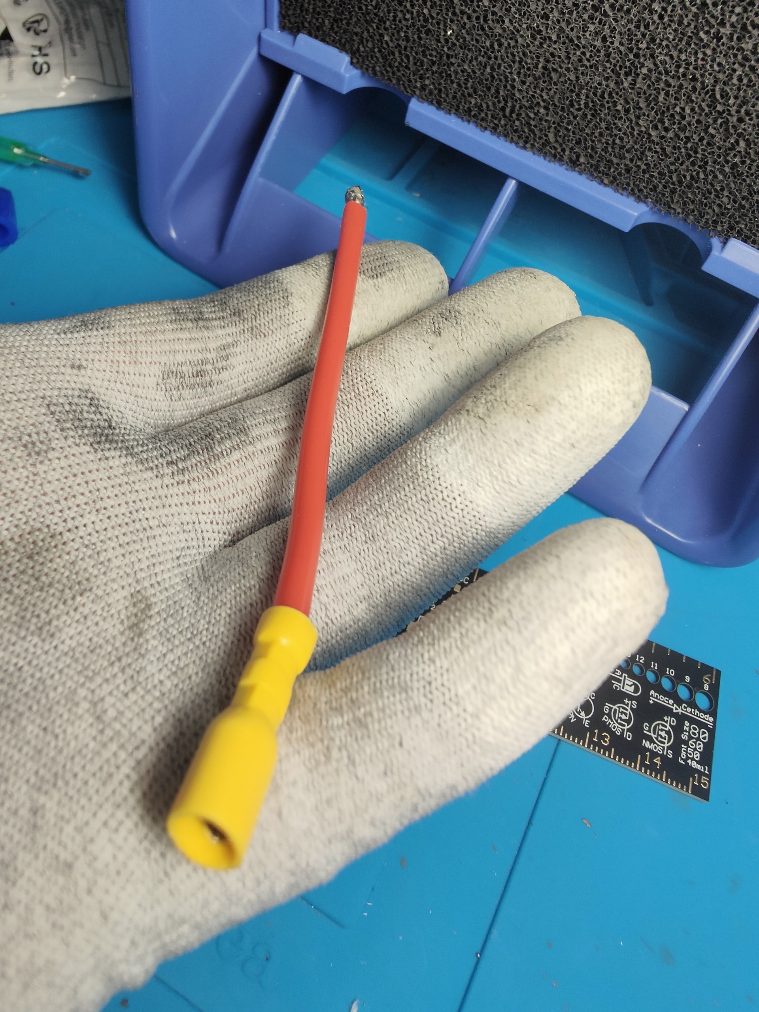
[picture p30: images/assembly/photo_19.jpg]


Solder the wire to the appropriate PCB pad (use the reference above to figure out **pad, length and wire colors** to use):

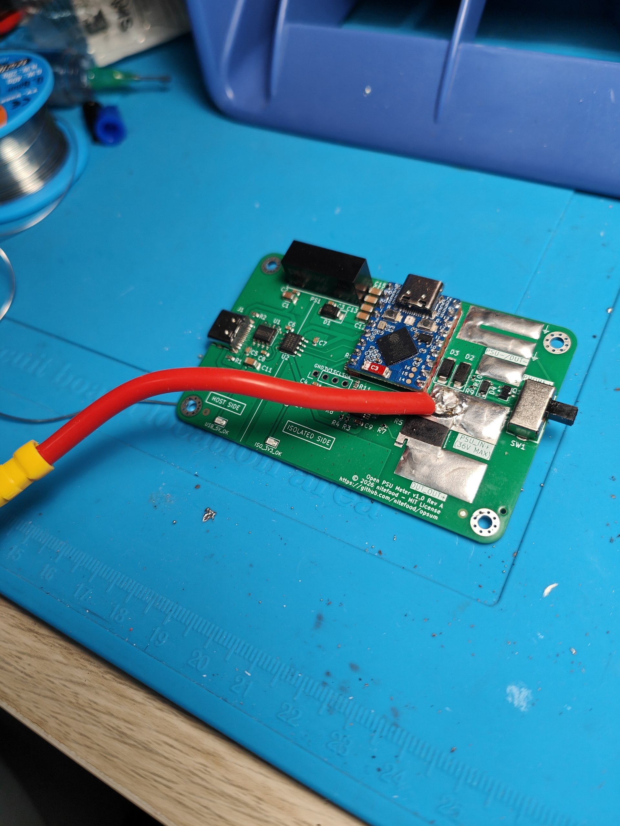
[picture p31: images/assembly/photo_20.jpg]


Eventually the board should look like this. Make sure the Probe+ wire doesn't touch the black wires above.

**Note that the black wires are shorted together, so they can be touching each other without problems**:

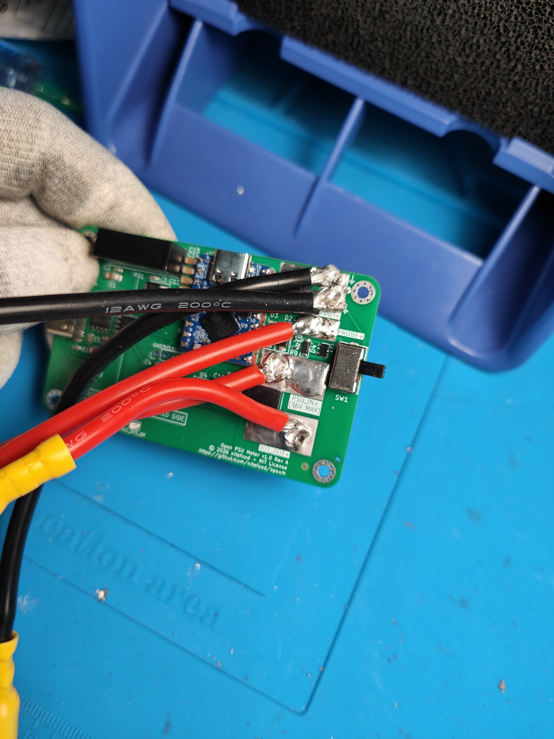
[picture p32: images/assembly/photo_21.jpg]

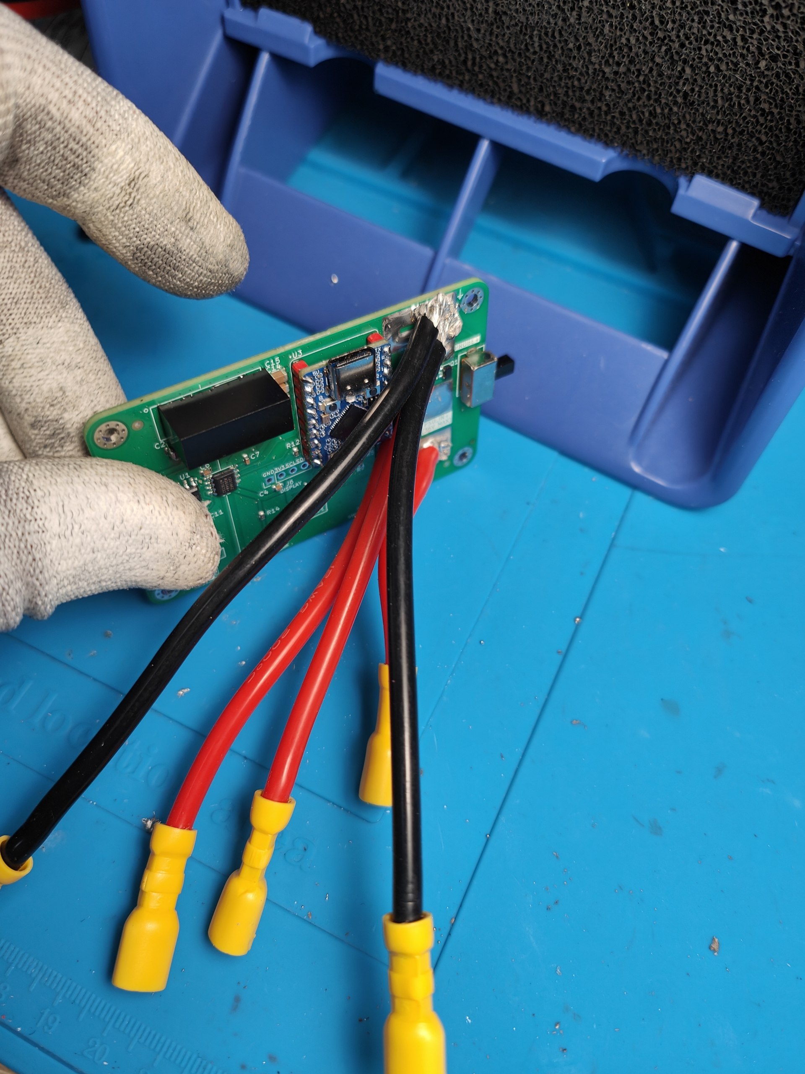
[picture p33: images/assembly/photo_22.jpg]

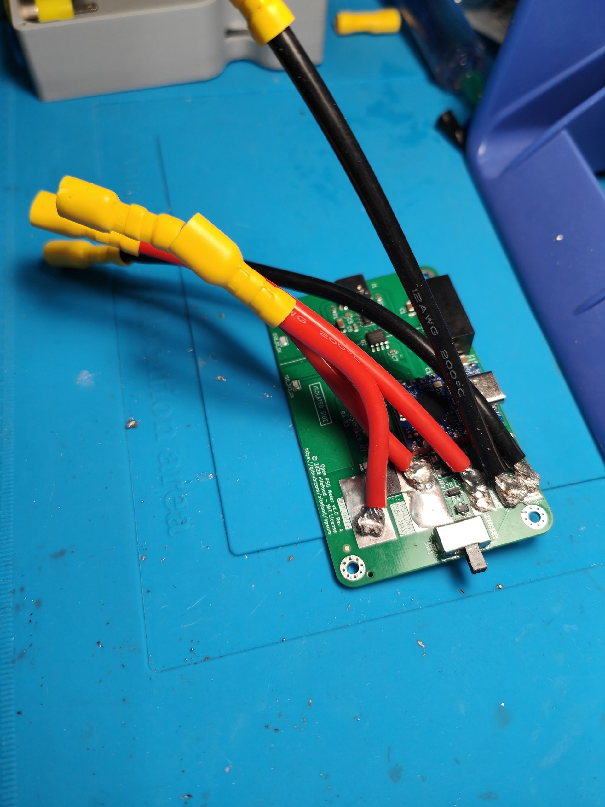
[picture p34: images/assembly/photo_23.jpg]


---

### 7. Flash the firmware to the ESP32-S3 MCU

Connect a USB-C cable **from your PC to the MCU USBC PORT** _(Note: make sure you connect to the **MCU USB port, not the other (isolated) USB port**, otherwise your PC won't recognize the ESP32 board)_

Then flash the `firmware-s3-FULL.bin` on the board using `esptool`. 

> Detailed step-by-step instructions can be found [here](../dist#what-each-binary-is-for).

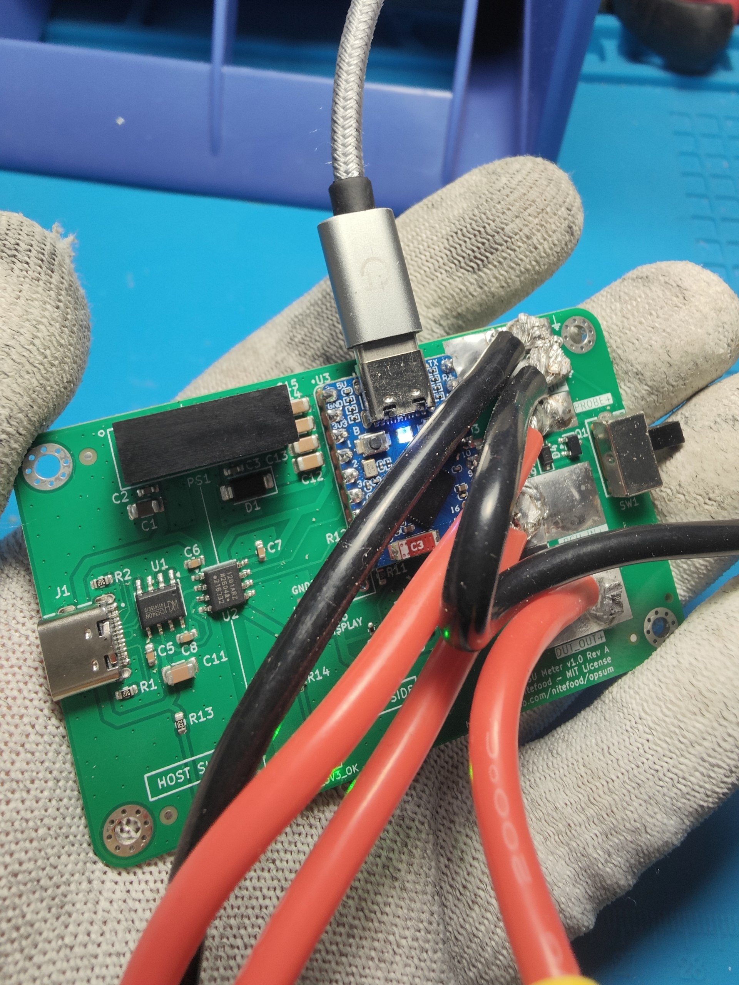
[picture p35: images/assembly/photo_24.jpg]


---

### 8. Insert the PCB into the case and connect the sockets

Place the PCB in the enclosure base, and secure it using **four M2.5 screws**:

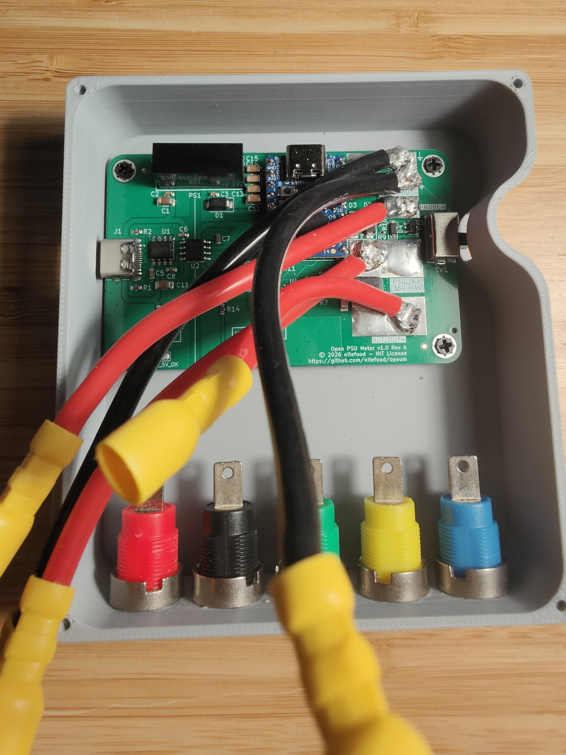
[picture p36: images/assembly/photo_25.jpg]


Then connect each cable to its matching socket.

> Note: the sequence to follow is, from left to right:
>
> **| PSU+ | PSU- | PROBE+ | DUT+ | DUT- |**
> 
> You can also reference the socket names as printed on the enclosure lid.

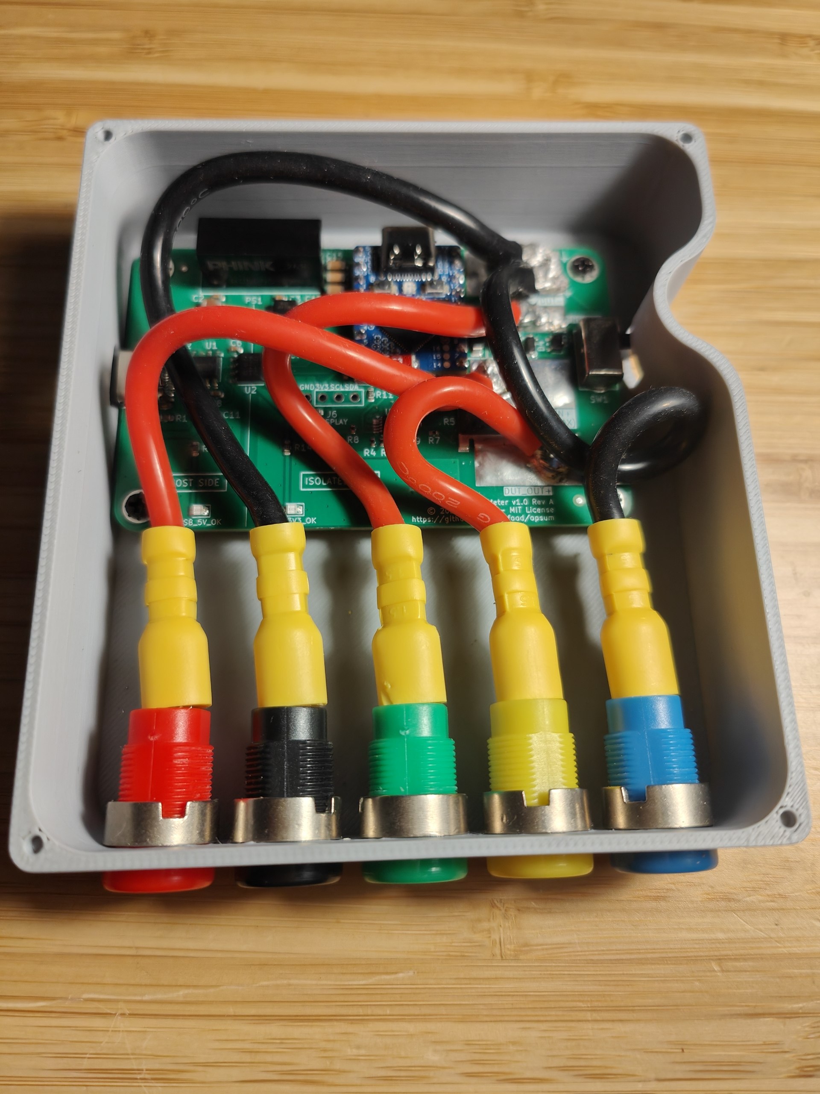
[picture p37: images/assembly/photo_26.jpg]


Finally, place the lid _(make sure the led guides fit between the wires, if you installed them)_ and secure it with **four M2.5 screws**:

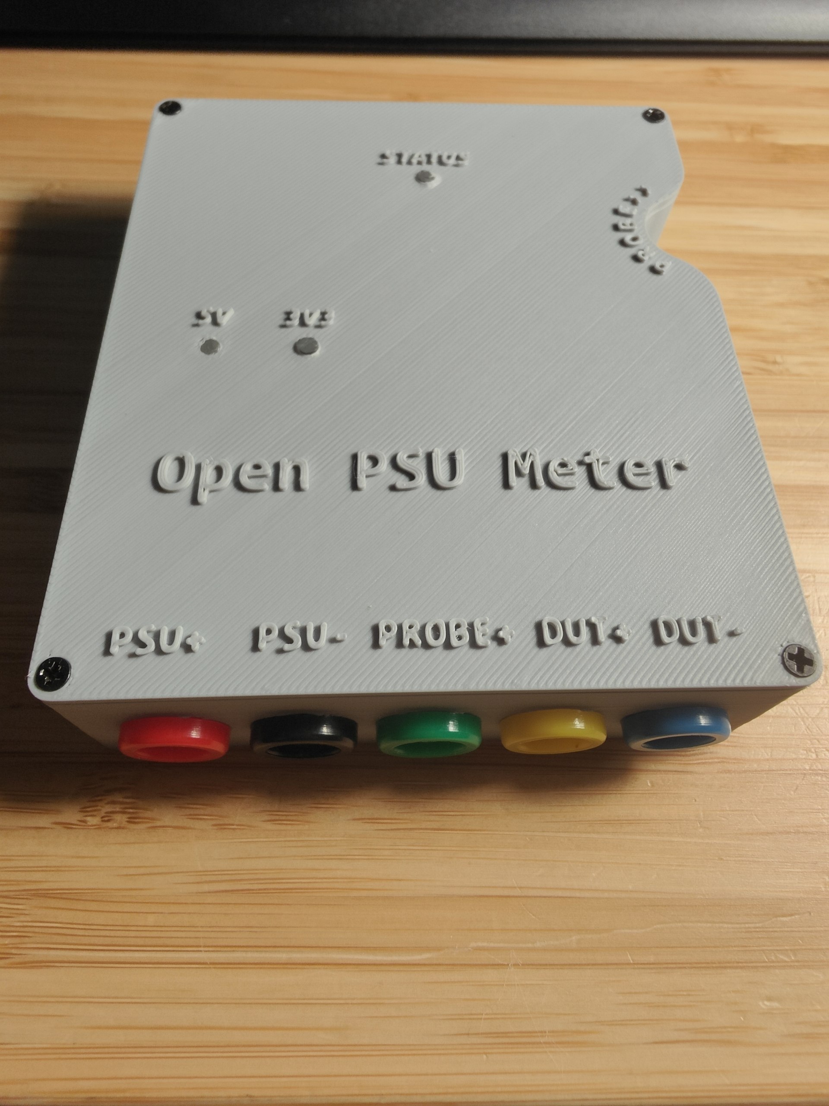
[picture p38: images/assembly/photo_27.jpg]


Connect the board's isolated USBC port to the PC, and connect to it using the included [GUI](../dist/opsum_gui.exe) or one of the [third party tools](../third_party_tools)

> Note: if your PC doesn't recognize the board as a COM port, make sure you have the correct CH340 drivers installed. These are the official driver download links depending on your OS:
>
> [Windows](https://www.wch-ic.com/downloads/CH341SER_EXE.html) - [Linux](https://www.wch-ic.com/downloads/CH341SER_LINUX_ZIP.html) - [MacOS](https://www.wch-ic.com/downloads/CH341SER_MAC_ZIP.html)

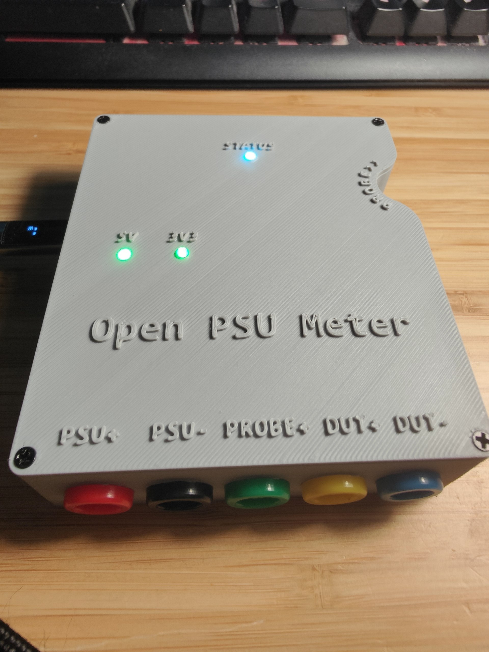
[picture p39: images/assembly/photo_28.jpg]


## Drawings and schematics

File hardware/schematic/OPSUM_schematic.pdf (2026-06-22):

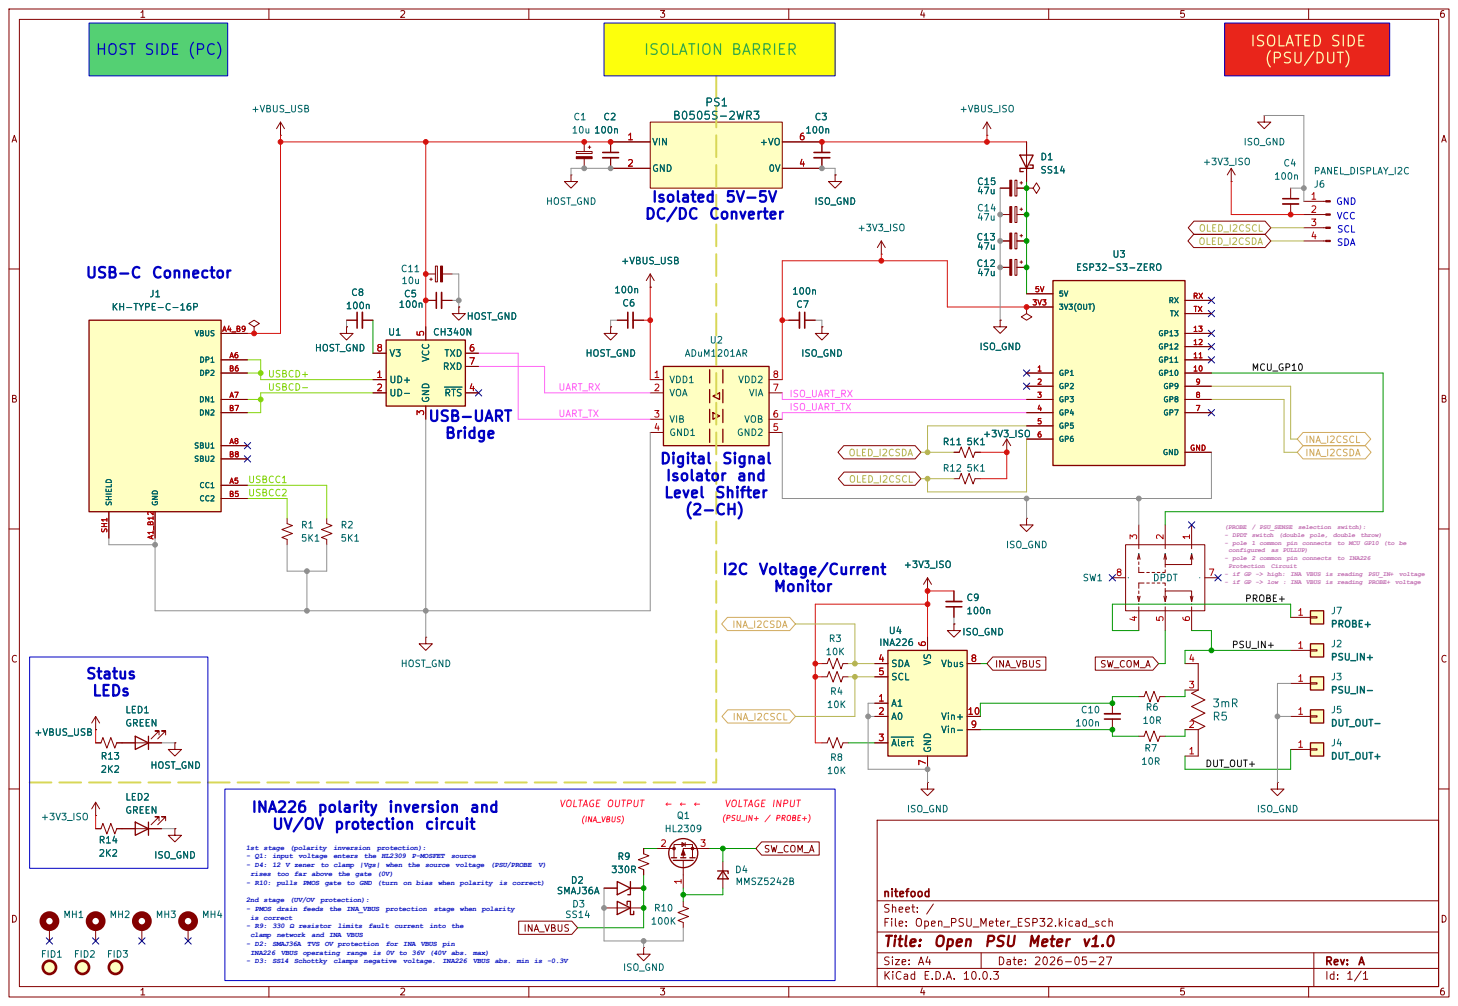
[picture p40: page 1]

(PSU/DUT) HOST SIDE (PC)

SCL SDA USB-UART

(PROBE / PSU_SENSE selection switch):
- DPDT switch (double pole, double throw)
- pole 1 common pin connects to MCU GP10 (to be
configured as PULLUP)
- pole 2 common pin connects to INA226
Protection Circuit
- if GP -> high: INA VBUS is reading PSU_IN+ voltage

- if GP -> low : INA VBUS is reading PROBE+ voltage Status

LEDs | ISO_GND +VBUS_USB R13 HOST_GND 2K2 2K2

INA226 polarity inversion and
(PSU_IN+ / PROBE+) 1st stage (polarity inversion protection):
UV/OV protection circuit

R14 R14 2K2 | ISO_GND

- Q1: input voltage enters the HL2309 P-MOSFET source
- D4: 12 V zener to clamp |Vgs| when the source voltage (PSU/PROBE V)
rises too far above the gate (0V)
- R10: pulls PMOS gate to GND (turn on bias when polarity is correct)

2nd stage (UV/OV protection):
- PMOS drain feeds the INA_VBUS protection stage when polarity
is correct
- R9: 330 Ω resistor limits fault current into the
clamp network and INA VBUS
- D2: SMAJ36A TVS OV protection for INA VBUS pin
INA226 VBUS operating range is 0V to 36V (40V abs. max)
- D3: SS14 Schottky clamps negative voltage. INA226 VBUS abs. min is -0.3V

Size: A4 | Rev: A
KiCad E.D.A. 10.0.3 | Id: 1/1

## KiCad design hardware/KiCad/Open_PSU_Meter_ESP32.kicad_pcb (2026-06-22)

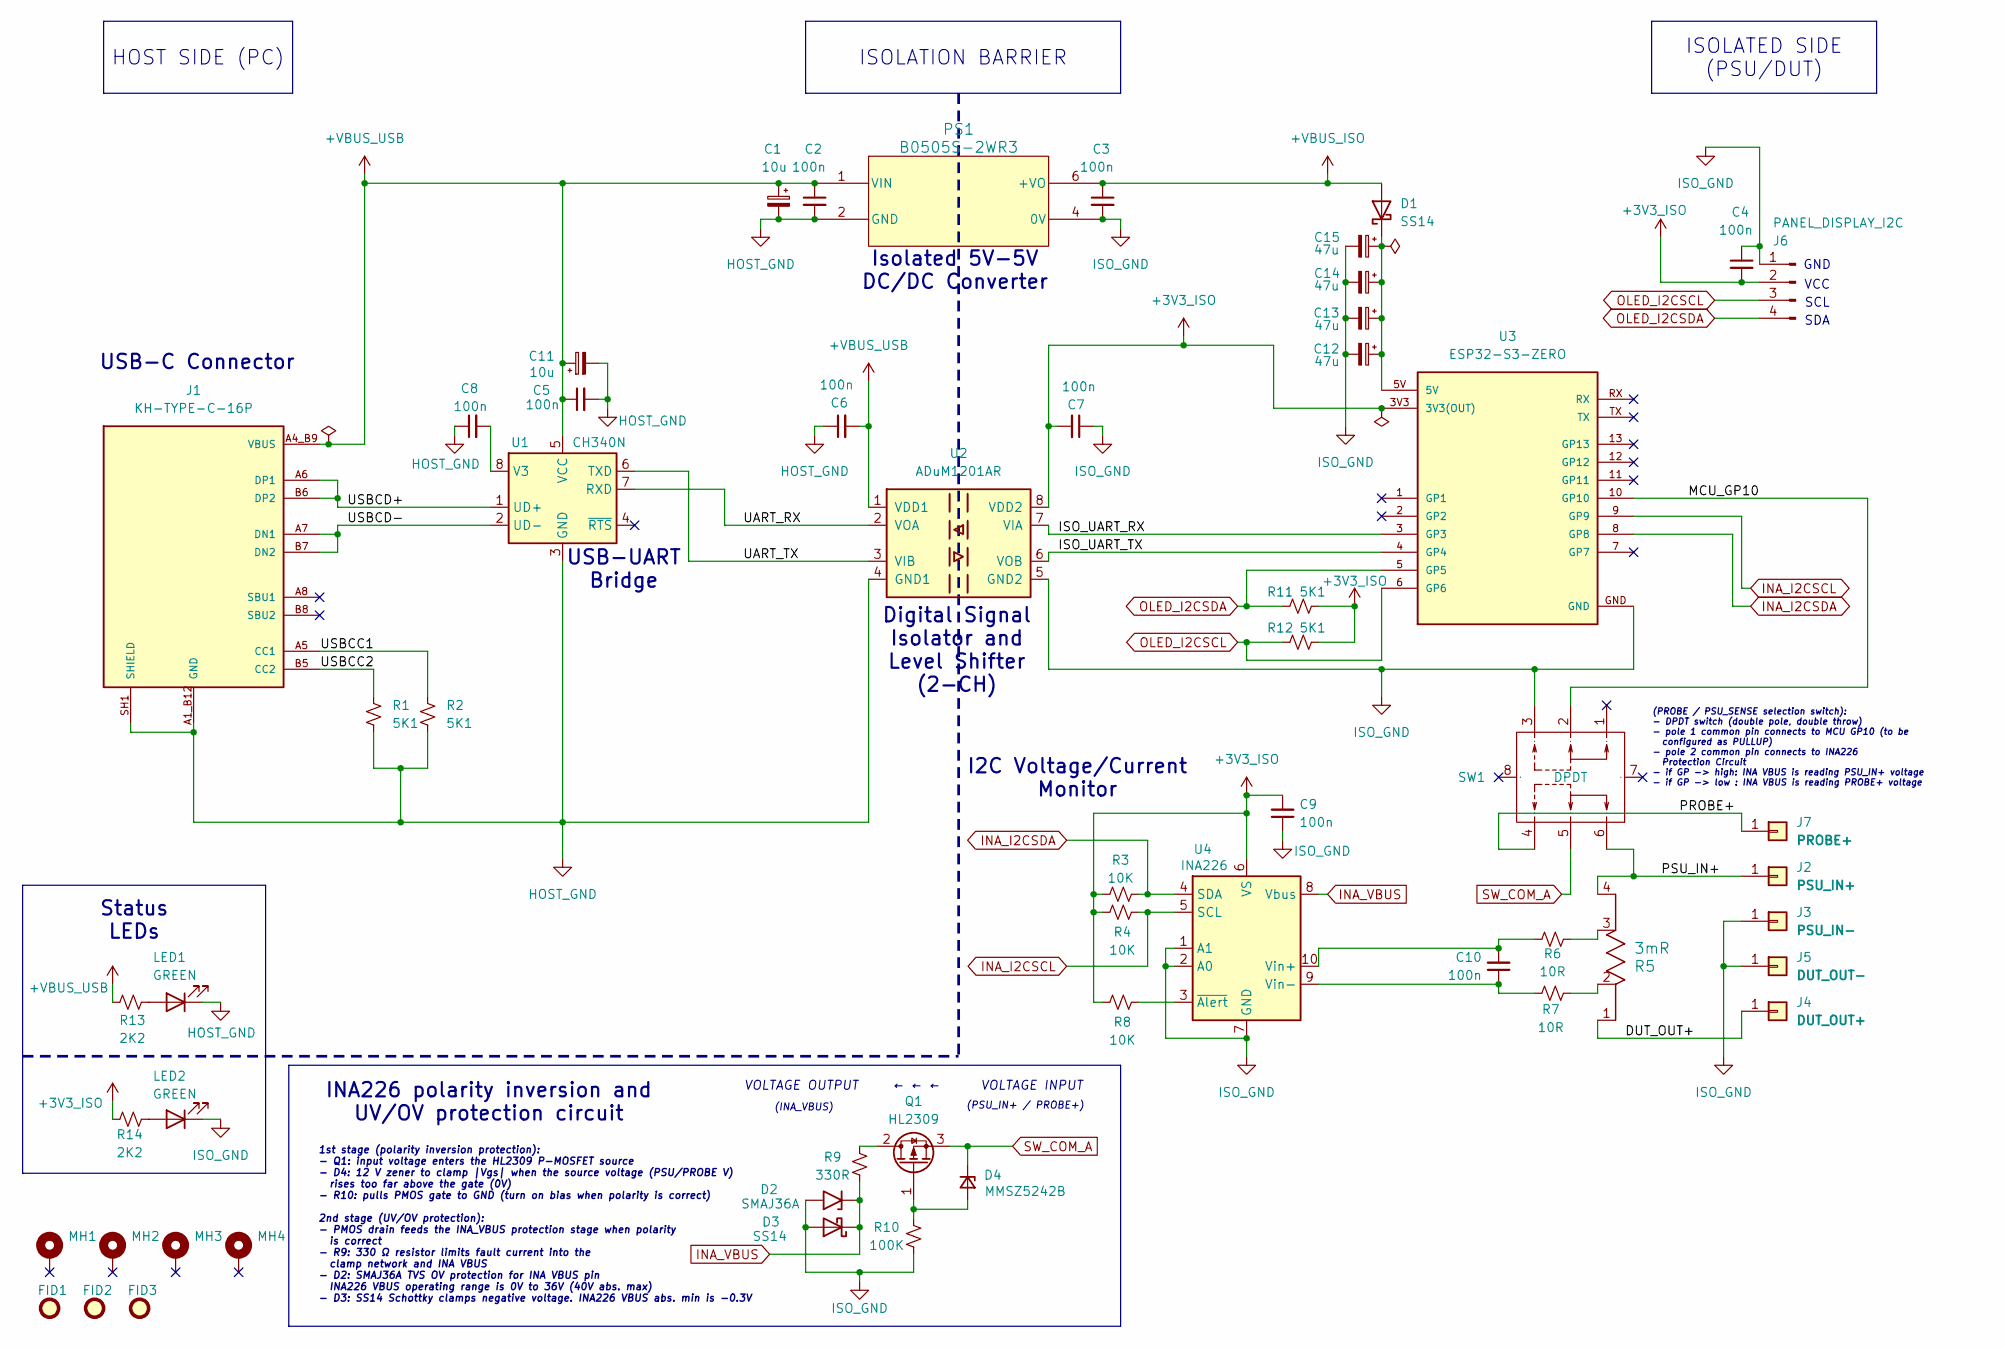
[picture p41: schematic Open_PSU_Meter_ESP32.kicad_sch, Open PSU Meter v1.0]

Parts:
C1, C11: 10u; C_1206_3216Metric; Manufacturer Part Number CL31A106KBHNNNE; LCSC C13585
C2, C3, C4, C5, C6, C7, C8, C9, C10: 100n; C_0603_1608Metric; Manufacturer Part Number CC0603KRX7R9BB104; LCSC C14663
C12, C13, C14, C15: 47u; C_1206_3216Metric; Manufacturer Part Number CL31A476MPHNNNE; LCSC C96123
D1, D3: SS14; D_SMA; Manufacturer Part Number SS14; LCSC C2480
D2: SMAJ36A; D_SMA; Manufacturer Part Number SMAJ36A; LCSC C19077550
D4: MMSZ5242B; D_SOD-123; Manufacturer Part Number MMSZ5242B; LCSC C19077426
FID1, FID2, FID3: Fiducial; Fiducial_1mm_Mask2mm
J1: KH-TYPE-C-16P; KINGHELM_KH-TYPE-C-16P; PARTREV A0; LCSC C709357
J2: PSU_IN+
J3: PSU_IN-
J4: DUT_OUT+
J5: DUT_OUT-
J6: PANEL_DISPLAY_I2C; PinHeader_1x04_P2.54mm_Vertical
J7: PROBE+
LED1, LED2: GREEN; LED_0805_2012Metric; Manufacturer Part Number KT-0805G; LCSC C2297
MH1, MH2, MH3, MH4: MountingHole_Pad; MountingHole_2.7mm_M2.5_Pad_Via
PS1: B0505S-2WR3; B_S-2WR2_MNS
Q1: HL2309; SOT-23-3; Manufacturer Part Number HL2309; LCSC C28646263
R1, R2, R11, R12: 5K1; R_0603_1608Metric; Manufacturer Part Number 0603WAF5101T5E; LCSC C23186
R3, R4, R8: 10K; R_0402_1005Metric; Manufacturer Part Number 0402WGF1002TCE; LCSC C25744
R5: 3mR; WSL3637_VIS; Manufacturer Part Number WSL36373L000FEA; LCSC C844085
R6, R7: 10R; R_0402_1005Metric; Manufacturer Part Number TC0225B100JTCC; LCSC C517445
R9: 330R; R_0402_1005Metric; Manufacturer Part Number 0402WGF3300TCE; LCSC C25104
R10: 100K; R_0402_1005Metric; Manufacturer Part Number 0402WGF1003TCE; LCSC C25741
R13, R14: 2K2; R_0603_1608Metric; Manufacturer Part Number 0603WAF2201T5E; LCSC C4190
SW1: DPDT; SW-TH_SK22D02G5; Manufacturer Part SK22D02G5; LCSC Part Name SK22D02G5
U1: CH340N; JEITA_SOIC-8_3.9x4.9mm_P1.27mm; Manufacturer Part Number CH340N; LCSC C2977777
U2: ADuM1201AR; SOIC-8_3.9x4.9mm_P1.27mm; Manufacturer Part Number ADUM1201ARZ-RL7; LCSC C9669
U3: ESP32-S3-ZERO; MODULE_ESP32-S3-ZERO; PARTREV NA
U4: INA226; TSSOP-10_3x3mm_P0.5mm; Manufacturer Part Number INA226AIDGSR; LCSC C49851

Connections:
+3V3_ISO: C4.2, C7.2, C9.2, J6.2, R3.1, R4.2, R8.2, R11.1, R12.1, R14.2, U2.8 (VDD2), U3.3V3 (3V3(OUT)), U4.6 (VS)
+VBUS_ISO: C3.1, D1.2 (A), PS1.6 (+VO)
+VBUS_USB: C1.1, C2.1, C5.1, C6.2, C11.1, J1.A4_B9 (VBUS), J1.A9_B4 (VBUS), PS1.1 (VIN), R13.1, U1.5 (VCC), U2.1 (VDD1)
/DUT_OUT+: J4.1, R5.1
/ISO_UART_RX: U2.7 (VIA), U3.3 (GP3)
/ISO_UART_TX: U2.6 (VOB), U3.4 (GP4)
/MCU_GP10: SW1.2, U3.10 (GP10)
/PROBE+: J7.1, SW1.4
/PSU_IN+: J2.1, R5.4, SW1.6
/UART_RX: U1.7 (RXD), U2.2 (VOA)
/UART_TX: U1.6 (TXD), U2.3 (VIB)
/USBCC1: J1.A5 (CC1), R2.1
/USBCC2: J1.B5 (CC2), R1.1
/USBCD+: J1.A6 (DP1), J1.B6 (DP2), U1.1 (UD+)
/USBCD-: J1.A7 (DN1), J1.B7 (DN2), U1.2 (UD-)
HOST_GND: C1.2, C2.2, C5.2, C6.1, C8.1, C11.2, J1.A1_B12 (GND), J1.A12_B1 (GND), J1.SH1 (SHIELD), J1.SH2 (SHIELD), J1.SH3 (SHIELD), J1.SH4 (SHIELD), LED1.1 (K), PS1.2 (GND), R1.2, R2.2, U1.3 (GND), U2.4 (GND1)
INA_I2CSCL: R4.1, U3.9 (GP9), U4.5 (SCL)
INA_I2CSDA: R3.2, U3.8 (GP8), U4.4 (SDA)
INA_VBUS: D2.1 (A1), D3.1 (K), R9.1, U4.8 (Vbus)
ISO_GND: C3.2, C4.1, C7.1, C9.1, C12.2, C13.2, C14.2, C15.2, D2.2 (A2), D3.2 (A), J3.1, J5.1, J6.1, LED2.1 (K), PS1.4 (0V), R10.2, SW1.3, U2.5 (GND2), U3.GND, U4.1 (A1), U4.2 (A0), U4.7 (GND)
unnamed: C12.1, C13.1, C14.1, C15.1, D1.1 (K), U3.5V
unnamed: D4.2 (A), Q1.1 (G), R10.1
unnamed: LED1.2 (A), R13.2
unnamed: LED2.2 (A), R14.1
unnamed: Q1.2 (D), R9.2
unnamed: R5.2, R7.2
unnamed: R5.3, R6.2
unnamed: C8.2, U1.8 (V3)
unnamed: C10.2, R6.1, U4.10 (Vin+)
unnamed: C10.1, R7.1, U4.9 (Vin-)
unnamed: R8.1, U4.3 (~Alert)
OLED_I2CSCL: J6.3, R12.2, U3.6 (GP6)
OLED_I2CSDA: J6.4, R11.2, U3.5 (GP5)
SW_COM_A: D4.1 (K), Q1.3 (S), SW1.5

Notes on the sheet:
SCL
(INA_VBUS)
(PSU_IN+ / PROBE+)
I2C Voltage/Current Monitor
Isolated 5V-5V DC/DC Converter
SDA
Status LEDs
Digital Signal Isolator and Level Shifter (2-CH)
VCC
VOLTAGE OUTPUT ← ← ← VOLTAGE INPUT
GND
INA226 polarity inversion and UV/OV protection circuit
1st stage (polarity inversion protection): - Q1: input voltage enters the HL2309 P-MOSFET source - D4: 12 V zener to clamp |Vgs| when the source voltage (PSU/PROBE V) rises too far above the gate (0V) - R10: pulls PMOS gate to GND (turn on bias when polarity is correct) 2nd stage (UV/OV protection)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
USB-UART Bridge
(PROBE / PSU_SENSE selection switch): - DPDT switch (double pole, double throw) - pole 1 common pin connects to MCU GP10 (to be configured as PULLUP) - pole 2 common pin connects to INA226 Protection Circuit - if GP -> high: INA VBUS is reading PSU_IN+ voltage - if GP -> low : INA VBUS is reading P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
USB-C Connector
ISOLATED SIDE (PSU/DUT)
HOST SIDE (PC)
ISOLATION BARRIER

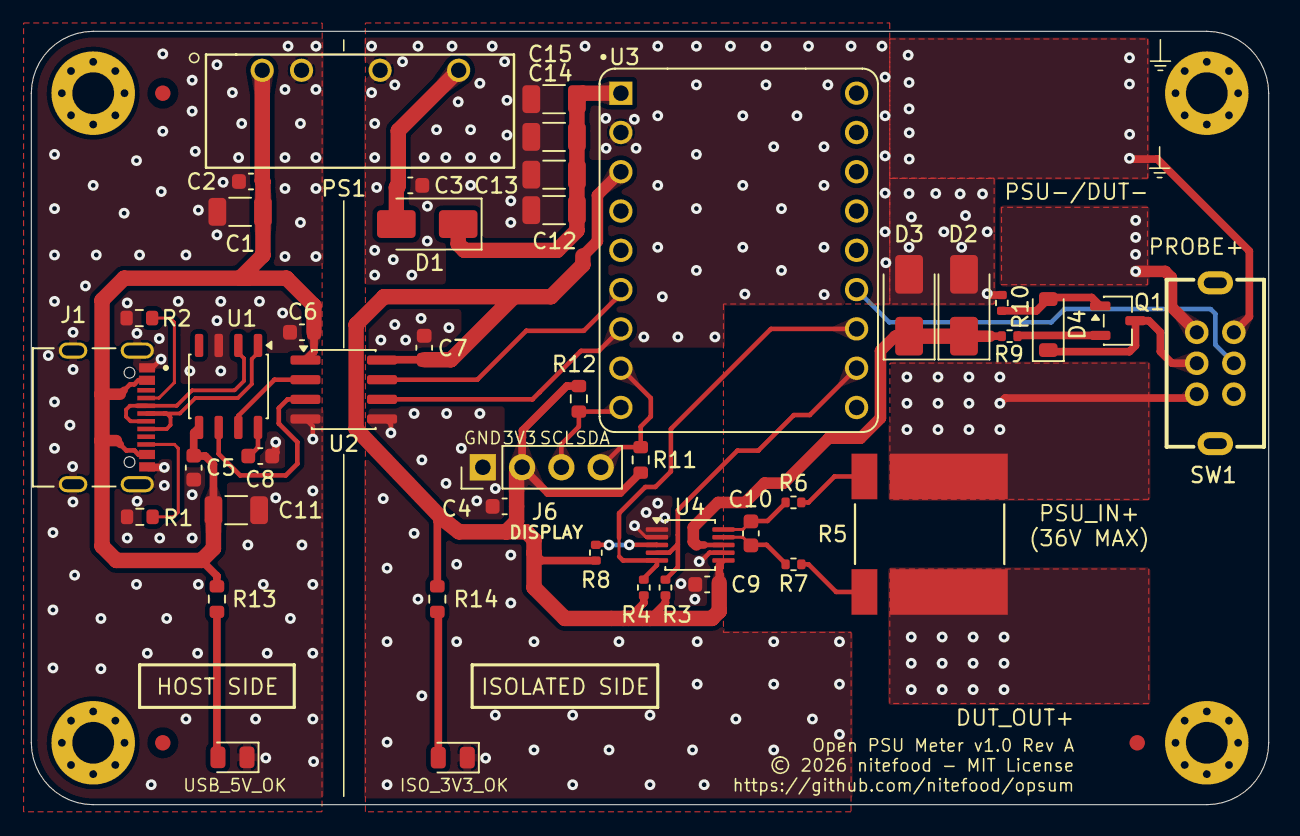
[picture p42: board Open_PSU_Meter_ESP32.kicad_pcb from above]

Board: 2 copper layers, 80.0 x 50.0 mm, 51 parts (0 on the bottom side), 32 nets.

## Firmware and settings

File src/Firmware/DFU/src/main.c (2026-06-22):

#include <stdbool.h>
#include <stddef.h>
#include <stdint.h>
#include <string.h>

#include "driver/gpio.h"
#include "driver/rmt_encoder.h"
#include "driver/rmt_tx.h"
#include "driver/uart.h"
#include "esp_crc.h"
#include "esp_err.h"
#include "esp_idf_version.h"
#include "esp_log.h"
#include "esp_ota_ops.h"
#include "esp_partition.h"
#include "esp_rom_crc.h"
#include "esp_system.h"
#include "esp_task_wdt.h"
#include "esp_timer.h"

#define DFU_UART_NUM                UART_NUM_1
#define DFU_UART_TX_PIN             GPIO_NUM_3
#define DFU_UART_RX_PIN             GPIO_NUM_4
#define DFU_UART_BAUD               921600

#define DFU_STATUS_LED_GPIO         GPIO_NUM_21
#define DFU_LED_ACTIVE_BLINK_MS     150
#define DFU_LED_BRIGHTNESS          24

#define WS2812_RMT_RES_HZ           10000000UL
#define WS2812_T0H_NS               350UL
#define WS2812_T0L_NS               900UL
#define WS2812_T1H_NS               900UL
#define WS2812_T1L_NS               350UL
#define WS2812_RESET_US             80UL
#define WS2812_BITS_PER_LED         24U
#define WS2812_SYMBOLS_PER_LED      (WS2812_BITS_PER_LED + 1U)

#define DFU_SYNC_0                  0x44U
#define DFU_SYNC_1                  0x46U
#define DFU_PROTO_VER               0x01U

#define DFU_CMD_HELLO               0x01U
#define DFU_CMD_HELLO_RSP           0x02U
#define DFU_CMD_BEGIN               0x10U
#define DFU_CMD_BEGIN_RSP           0x11U
#define DFU_CMD_DATA                0x20U
#define DFU_CMD_DATA_RSP            0x21U
#define DFU_CMD_END                 0x30U
#define DFU_CMD_END_RSP             0x31U
#define DFU_CMD_STATUS              0x40U
#define DFU_CMD_STATUS_RSP          0x41U
#define DFU_CMD_ABORT               0x50U
#define DFU_CMD_ABORT_RSP           0x51U
#define DFU_CMD_REBOOT              0x60U
#define DFU_CMD_REBOOT_RSP          0x61U

#define DFU_STATUS_OK               0x0000U
#define DFU_STATUS_BAD_FRAME_CRC    0x0001U
#define DFU_STATUS_UNSUPPORTED_VER  0x0002U
#define DFU_STATUS_UNKNOWN_CMD      0x0003U
#define DFU_STATUS_INVALID_STATE    0x0004U
#define DFU_STATUS_INVALID_ARG      0x0005U
#define DFU_STATUS_OVERSIZE_IMAGE   0x0006U
#define DFU_STATUS_PARTITION_ERROR  0x0007U
#define DFU_STATUS_FLASH_WRITE_ERR  0x0008U
#define DFU_STATUS_FINAL_CRC_MISM   0x0009U
#define DFU_STATUS_SEQ_MISMATCH     0x000AU
#define DFU_STATUS_OFFSET_MISMATCH  0x000BU
#define DFU_STATUS_TIMEOUT          0x000CU
#define DFU_STATUS_BUSY             0x000DU
#define DFU_STATUS_UNSUP_TARGET     0x000EU
#define DFU_STATUS_IMAGE_INVALID    0x000FU
#define DFU_STATUS_ABORT_DONE       0x0010U

#define DFU_STATE_IDLE              0U
#define DFU_STATE_READY             1U
#define DFU_STATE_RECEIVING         2U
#define DFU_STATE_VERIFYING         3U
#define DFU_STATE_COMMITTED         4U
#define DFU_STATE_ERROR             5U

#define DFU_TARGET_DFU_APP          0x00U
#define DFU_TARGET_MAIN_APP         0x01U
#define DFU_FLAGS_STORAGE_ERASE     0x01U

#define DFU_MAX_CHUNK               4096U
#define DFU_MAX_PAYLOAD             4104U
#define DFU_FRAME_TIMEOUT_MS        2000
#define DFU_SESSION_TIMEOUT_MS      20000

#define ESP_IMAGE_MAGIC             0xE9U

typedef struct {
	uint8_t ver;
	uint8_t cmd;
	uint16_t seq;
	uint16_t len;
	uint8_t payload[DFU_MAX_PAYLOAD];
} dfu_frame_t;

typedef struct __attribute__((packed)) {
	uint8_t proto_version;
	uint8_t chip_id;
	uint8_t flags;
	uint8_t reserved;
	uint32_t dfu_fw_version;
	uint32_t max_chunk;
	uint32_t app_partition_size;
	uint32_t storage_partition_size;
} hello_rsp_t;

typedef struct __attribute__((packed)) {
	uint32_t total_size;
	uint32_t chunk_size;
	uint32_t expected_crc32;
	uint8_t target_id;
	uint8_t options;
	uint16_t reserved;
	uint32_t version_code;
} begin_req_t;

typedef struct __attribute__((packed)) {
	uint32_t offset;
	uint16_t data_len;
	uint16_t reserved;
} data_req_hdr_t;

typedef struct __attribute__((packed)) {
	uint32_t next_offset;
	uint32_t running_crc32;
	uint16_t status;
	uint16_t reserved;
} data_rsp_t;

typedef struct __attribute__((packed)) {
	uint16_t status;
	uint16_t reserved;
} generic_rsp_t;

typedef struct __attribute__((packed)) {
	uint32_t final_size;
	uint32_t final_crc32;
} end_req_t;

typedef struct __attribute__((packed)) {
	uint8_t state;
	uint8_t reserved0;
	uint16_t last_error;
	uint32_t bytes_received;
	uint32_t expected_size;
} status_rsp_t;

static const char *TAG = "dfu";

static const esp_partition_t *s_dfu_part = NULL;
static const esp_partition_t *s_main_app_part = NULL;
static const esp_partition_t *s_storage_part = NULL;

static uint8_t s_state = DFU_STATE_IDLE;
static uint16_t s_last_error = DFU_STATUS_OK;
static uint16_t s_expected_seq = 0;
static int64_t s_last_activity_us = 0;
static int64_t s_last_heartbeat_us = 0;

static rmt_channel_handle_t s_led_rmt_chan = NULL;
static rmt_encoder_handle_t s_led_rmt_encoder = NULL;
static rmt_symbol_word_t s_led_symbols[WS2812_SYMBOLS_PER_LED];
static bool s_led_on = false;
static int64_t s_last_led_toggle_us = 0;

static uint32_t s_expected_size = 0;
static uint32_t s_expected_crc32 = 0;
static uint32_t s_bytes_received = 0;
static uint32_t s_crc_running = 0xFFFFFFFFU;
static bool s_image_header_seen = false;

/* Keep larger protocol buffers in static storage to avoid task-stack pressure. */
static dfu_frame_t s_frame;
static uint8_t s_crc_input_buf[6 + DFU_MAX_PAYLOAD];

static uint16_t le16(const uint8_t *p)
{
	return (uint16_t)p[0] | ((uint16_t)p[1] << 8);
}

static uint32_t le32(const uint8_t *p)
{
	return (uint32_t)p[0] | ((uint32_t)p[1] << 8) | ((uint32_t)p[2] << 16) | ((uint32_t)p[3] << 24);
}

static void wr16(uint8_t *p, uint16_t v)
{
	p[0] = (uint8_t)(v & 0xFFU);
	p[1] = (uint8_t)((v >> 8) & 0xFFU);
}

static void wr32(uint8_t *p, uint32_t v)
{
	p[0] = (uint8_t)(v & 0xFFU);
	p[1] = (uint8_t)((v >> 8) & 0xFFU);
	p[2] = (uint8_t)((v >> 16) & 0xFFU);
	p[3] = (uint8_t)((v >> 24) & 0xFFU);
}

static uint32_t dfu_crc32_calc(const uint8_t *data, size_t len)
{
	uint32_t crc = esp_rom_crc32_le(0xFFFFFFFFU, data, len);
	return crc ^ 0xFFFFFFFFU;
}

static uint32_t dfu_crc32_update(uint32_t running, const uint8_t *data, size_t len)
{
	return esp_rom_crc32_le(running, data, len);
}

static uint32_t dfu_crc32_finalize(uint32_t running)
{
	return running ^ 0xFFFFFFFFU;
}

static uint16_t ws2812_ns_to_ticks(uint32_t ns)
{
	uint64_t ticks = ((uint64_t)WS2812_RMT_RES_HZ * ns + 999999999ULL) / 1000000000ULL;
	if (ticks > 0xFFFFU) {
		ticks = 0xFFFFU;
	}
	return (uint16_t)ticks;
}

static void ws2812_encode_grb(uint8_t g, uint8_t r, uint8_t b)
{
	const uint16_t t0h = ws2812_ns_to_ticks(WS2812_T0H_NS);
	const uint16_t t0l = ws2812_ns_to_ticks(WS2812_T0L_NS);
	const uint16_t t1h = ws2812_ns_to_ticks(WS2812_T1H_NS);
	const uint16_t t1l = ws2812_ns_to_ticks(WS2812_T1L_NS);
	const uint16_t reset_ticks = (uint16_t)((WS2812_RMT_RES_HZ / 1000000UL) * WS2812_RESET_US);
	const uint32_t grb = ((uint32_t)g << 16) | ((uint32_t)r << 8) | (uint32_t)b;

	for (uint32_t i = 0; i < WS2812_BITS_PER_LED; i++) {
		bool one = ((grb >> (WS2812_BITS_PER_LED - 1U - i)) & 0x1U) != 0;
		s_led_symbols[i].level0 = 1;
		s_led_symbols[i].duration0 = one ? t1h : t0h;
		s_led_symbols[i].level1 = 0;
		s_led_symbols[i].duration1 = one ? t1l : t0l;
	}

	s_led_symbols[WS2812_BITS_PER_LED].level0 = 0;
	s_led_symbols[WS2812_BITS_PER_LED].duration0 = reset_ticks / 2U;
	s_led_symbols[WS2812_BITS_PER_LED].level1 = 0;
	s_led_symbols[WS2812_BITS_PER_LED].duration1 = reset_ticks - (reset_ticks / 2U);
}

static void status_led_apply(bool on)
{
	rmt_transmit_config_t tx_cfg = {
		.loop_count = 0,
	};

	if (s_led_rmt_chan == NULL || s_led_rmt_encoder == NULL) {
		return;
	}

	if (on) {
		ws2812_encode_grb(DFU_LED_BRIGHTNESS, DFU_LED_BRIGHTNESS, 0);
	} else {
		ws2812_encode_grb(0, 0, 0);
	}

	if (rmt_transmit(s_led_rmt_chan, s_led_rmt_encoder, s_led_symbols, sizeof(s_led_symbols), &tx_cfg) == ESP_OK) {
		rmt_tx_wait_all_done(s_led_rmt_chan, pdMS_TO_TICKS(20));
	}
}

static void status_led_service(void)
{
	const bool active_transfer = (s_state == DFU_STATE_RECEIVING) || (s_state == DFU_STATE_VERIFYING);
	const bool idle_or_ready = (s_state == DFU_STATE_IDLE) || (s_state == DFU_STATE_READY);
	const int64_t period_us = (int64_t)DFU_LED_ACTIVE_BLINK_MS * 1000;
	int64_t now_us = esp_timer_get_time();

	if (active_transfer) {
		if ((now_us - s_last_led_toggle_us) >= period_us) {
			s_led_on = !s_led_on;
			s_last_led_toggle_us = now_us;
			status_led_apply(s_led_on);
		}
		return;
	}

	if (idle_or_ready) {
		if (!s_led_on) {
			s_led_on = true;
			s_last_led_toggle_us = now_us;
			status_led_apply(true);
		}
		return;
	}

	if (s_led_on) {
		s_led_on = false;
		status_led_apply(false);
	}
}

static const char *state_to_str(uint8_t state)
{
	switch (state) {
		case DFU_STATE_IDLE: return "IDLE";
		case DFU_STATE_READY: return "READY";
		case DFU_STATE_RECEIVING: return "RECEIVING";
		case DFU_STATE_VERIFYING: return "VERIFYING";
		case DFU_STATE_COMMITTED: return "COMMITTED";
		case DFU_STATE_ERROR: return "ERROR";
		default: return "UNKNOWN";
	}
}

static void dfu_heartbeat_log_service(void)
{
	const int64_t period_us = 5000000;
	int64_t now_us = esp_timer_get_time();

	if ((now_us - s_last_heartbeat_us) >= period_us) {
		s_last_heartbeat_us = now_us;
		ESP_LOGW(TAG, "DFU alive: state=%s bytes=%lu/%lu last_err=0x%04X", state_to_str(s_state), (unsigned long)s_bytes_received, (unsigned long)s_expected_size, s_last_error);
	}
}

static uint8_t rsp_cmd_for(uint8_t cmd)
{
	switch (cmd) {
		case DFU_CMD_HELLO: return DFU_CMD_HELLO_RSP;
		case DFU_CMD_BEGIN: return DFU_CMD_BEGIN_RSP;
		case DFU_CMD_DATA: return DFU_CMD_DATA_RSP;
		case DFU_CMD_END: return DFU_CMD_END_RSP;
		case DFU_CMD_STATUS: return DFU_CMD_STATUS_RSP;
		case DFU_CMD_ABORT: return DFU_CMD_ABORT_RSP;
		case DFU_CMD_REBOOT: return DFU_CMD_REBOOT_RSP;
		default: return DFU_CMD_STATUS_RSP;
	}
}

static esp_err_t uart_read_exact(uint8_t *dst, size_t len, uint32_t timeout_ms)
{
	size_t got = 0;
	int64_t start_us = esp_timer_get_time();

	while (got < len) {
		int r = uart_read_bytes(DFU_UART_NUM, dst + got, len - got, pdMS_TO_TICKS(20));
		if (r > 0) {
			got += (size_t)r;
			start_us = esp_timer_get_time();
			continue;
		}

		int64_t now_us = esp_timer_get_time();
		if ((uint64_t)(now_us - start_us) > ((uint64_t)timeout_ms * 1000ULL)) {
			return ESP_ERR_TIMEOUT;
		}
		status_led_service();
		esp_task_wdt_reset();
	}

	return ESP_OK;
}

static esp_err_t dfu_send_frame(uint8_t cmd, uint16_t seq, const uint8_t *payload, uint16_t len)
{
	uint8_t header[8];
	uint8_t crc_bytes[4];

	if (len > DFU_MAX_PAYLOAD) {
		return ESP_ERR_INVALID_SIZE;
	}

	header[0] = DFU_SYNC_0;
	header[1] = DFU_SYNC_1;
	header[2] = DFU_PROTO_VER;
	header[3] = cmd;
	wr16(&header[4], seq);
	wr16(&header[6], len);

	memcpy(s_crc_input_buf, &header[2], 6);
	if (len > 0 && payload != NULL) {
		memcpy(&s_crc_input_buf[6], payload, len);
	}
	wr32(crc_bytes, dfu_crc32_calc(s_crc_input_buf, 6 + len));

	uart_write_bytes(DFU_UART_NUM, (const char *)header, sizeof(header));
	if (len > 0 && payload != NULL) {
		uart_write_bytes(DFU_UART_NUM, (const char *)payload, len);
	}
	uart_write_bytes(DFU_UART_NUM, (const char *)crc_bytes, sizeof(crc_bytes));
	uart_wait_tx_done(DFU_UART_NUM, pdMS_TO_TICKS(50));

	return ESP_OK;
}

static esp_err_t dfu_recv_frame(dfu_frame_t *f)
{
	uint8_t b = 0;
	uint8_t hdr[6];
	uint8_t crc_rx_bytes[4];
	uint32_t crc_rx;
	uint32_t crc_calc;
	bool sync_found = false;

	while (!sync_found) {
		if (uart_read_exact(&b, 1, DFU_FRAME_TIMEOUT_MS) != ESP_OK) {
			return ESP_ERR_TIMEOUT;
		}
		if (b != DFU_SYNC_0) {
			continue;
		}
		if (uart_read_exact(&b, 1, DFU_FRAME_TIMEOUT_MS) != ESP_OK) {
			return ESP_ERR_TIMEOUT;
		}
		if (b == DFU_SYNC_1) {
			sync_found = true;
		}
	}

	if (uart_read_exact(hdr, sizeof(hdr), DFU_FRAME_TIMEOUT_MS) != ESP_OK) {
		return ESP_ERR_TIMEOUT;
	}

	f->ver = hdr[0];
	f->cmd = hdr[1];
	f->seq = le16(&hdr[2]);
	f->len = le16(&hdr[4]);

	if (f->len > DFU_MAX_PAYLOAD) {
		return ESP_ERR_INVALID_SIZE;
	}

	if (f->len > 0) {
		if (uart_read_exact(f->payload, f->len, DFU_FRAME_TIMEOUT_MS) != ESP_OK) {
			return ESP_ERR_TIMEOUT;
		}
	}

	if (uart_read_exact(crc_rx_bytes, sizeof(crc_rx_bytes), DFU_FRAME_TIMEOUT_MS) != ESP_OK) {
		return ESP_ERR_TIMEOUT;
	}

	memcpy(s_crc_input_buf, hdr, sizeof(hdr));
	if (f->len > 0) {
		memcpy(&s_crc_input_buf[sizeof(hdr)], f->payload, f->len);
	}
	crc_calc = dfu_crc32_calc(s_crc_input_buf, sizeof(hdr) + f->len);
	crc_rx = le32(crc_rx_bytes);

	if (crc_calc != crc_rx) {
		return ESP_ERR_INVALID_CRC;
	}

	return ESP_OK;
}

static void reset_session(void)
{
	s_expected_size = 0;
	s_expected_crc32 = 0;
	s_bytes_received = 0;
	s_crc_running = 0xFFFFFFFFU;
	s_image_header_seen = false;
}

static esp_err_t erase_partition_full(const esp_partition_t *p)
{
	if (p == NULL) {
		return ESP_ERR_INVALID_ARG;
	}
	return esp_partition_erase_range(p, 0, p->size);
}

static void send_generic_status_rsp(uint8_t req_cmd, uint16_t req_seq, uint16_t status)
{
	generic_rsp_t rsp = {
		.status = status,
		.reserved = 0,
	};
	dfu_send_frame(rsp_cmd_for(req_cmd), req_seq, (const uint8_t *)&rsp, sizeof(rsp));
}

static void handle_hello(const dfu_frame_t *f)
{
	hello_rsp_t rsp = {
		.proto_version = DFU_PROTO_VER,
		.chip_id = 0x09,
		.flags = DFU_FLAGS_STORAGE_ERASE,
		.reserved = 0,
		.dfu_fw_version = 0x00010000,
		.max_chunk = DFU_MAX_CHUNK,
		.app_partition_size = s_main_app_part ? s_main_app_part->size : 0,
		.storage_partition_size = s_storage_part ? s_storage_part->size : 0,
	};

	s_state = DFU_STATE_READY;
	s_last_error = DFU_STATUS_OK;
	dfu_send_frame(DFU_CMD_HELLO_RSP, f->seq, (const uint8_t *)&rsp, sizeof(rsp));
}

static void handle_begin(const dfu_frame_t *f)
{
	begin_req_t req;

	if (f->len != sizeof(begin_req_t)) {
		send_generic_status_rsp(DFU_CMD_BEGIN, f->seq, DFU_STATUS_INVALID_ARG);
		return;
	}
	if (s_state == DFU_STATE_RECEIVING || s_state == DFU_STATE_VERIFYING) {
		send_generic_status_rsp(DFU_CMD_BEGIN, f->seq, DFU_STATUS_BUSY);
		return;
	}
	if (s_main_app_part == NULL || s_storage_part == NULL) {
		send_generic_status_rsp(DFU_CMD_BEGIN, f->seq, DFU_STATUS_PARTITION_ERROR);
		return;
	}

	memcpy(&req, f->payload, sizeof(req));

	if (req.target_id != DFU_TARGET_MAIN_APP) {
		send_generic_status_rsp(DFU_CMD_BEGIN, f->seq, DFU_STATUS_UNSUP_TARGET);
		return;
	}
	if (req.total_size == 0 || req.total_size > s_main_app_part->size) {
		send_generic_status_rsp(DFU_CMD_BEGIN, f->seq, DFU_STATUS_OVERSIZE_IMAGE);
		return;
	}
	if (req.chunk_size == 0 || req.chunk_size > DFU_MAX_CHUNK) {
		send_generic_status_rsp(DFU_CMD_BEGIN, f->seq, DFU_STATUS_INVALID_ARG);
		return;
	}

	if (erase_partition_full(s_main_app_part) != ESP_OK) {
		send_generic_status_rsp(DFU_CMD_BEGIN, f->seq, DFU_STATUS_PARTITION_ERROR);
		return;
	}

	reset_session();
	s_expected_size = req.total_size;
	s_expected_crc32 = req.expected_crc32;
	s_state = DFU_STATE_RECEIVING;
	s_last_error = DFU_STATUS_OK;

	send_generic_status_rsp(DFU_CMD_BEGIN, f->seq, DFU_STATUS_OK);
}

static void handle_data(const dfu_frame_t *f)
{
	data_req_hdr_t hdr;
	data_rsp_t rsp;
	const uint8_t *chunk;
	esp_err_t err;

	rsp.next_offset = s_bytes_received;
	rsp.running_crc32 = dfu_crc32_finalize(s_crc_running);
	rsp.status = DFU_STATUS_OK;
	rsp.reserved = 0;

	if (s_state != DFU_STATE_RECEIVING) {
		rsp.status = DFU_STATUS_INVALID_STATE;
		dfu_send_frame(DFU_CMD_DATA_RSP, f->seq, (const uint8_t *)&rsp, sizeof(rsp));
		return;
	}
	if (f->len < sizeof(data_req_hdr_t)) {
		rsp.status = DFU_STATUS_INVALID_ARG;
		dfu_send_frame(DFU_CMD_DATA_RSP, f->seq, (const uint8_t *)&rsp, sizeof(rsp));
		return;
	}

	memcpy(&hdr, f->payload, sizeof(hdr));
	chunk = &f->payload[sizeof(hdr)];

	if ((uint16_t)(f->len - sizeof(hdr)) != hdr.data_len) {
		rsp.status = DFU_STATUS_INVALID_ARG;
		dfu_send_frame(DFU_CMD_DATA_RSP, f->seq, (const uint8_t *)&rsp, sizeof(rsp));
		return;
	}
	if (hdr.offset != s_bytes_received) {
		rsp.status = DFU_STATUS_OFFSET_MISMATCH;
		dfu_send_frame(DFU_CMD_DATA_RSP, f->seq, (const uint8_t *)&rsp, sizeof(rsp));
		return;
	}
	if (((uint64_t)s_bytes_received + hdr.data_len) > s_expected_size) {
		rsp.status = DFU_STATUS_OVERSIZE_IMAGE;
		dfu_send_frame(DFU_CMD_DATA_RSP, f->seq, (const uint8_t *)&rsp, sizeof(rsp));
		return;
	}

	if (!s_image_header_seen && hdr.offset == 0 && hdr.data_len > 0 && chunk[0] == ESP_IMAGE_MAGIC) {
		s_image_header_seen = true;
	}

	err = esp_partition_write(s_main_app_part, hdr.offset, chunk, hdr.data_len);
	if (err != ESP_OK) {
		rsp.status = DFU_STATUS_FLASH_WRITE_ERR;
		dfu_send_frame(DFU_CMD_DATA_RSP, f->seq, (const uint8_t *)&rsp, sizeof(rsp));
		return;
	}

	s_crc_running = dfu_crc32_update(s_crc_running, chunk, hdr.data_len);
	s_bytes_received += hdr.data_len;

	rsp.next_offset = s_bytes_received;
	rsp.running_crc32 = dfu_crc32_finalize(s_crc_running);
	rsp.status = DFU_STATUS_OK;

	dfu_send_frame(DFU_CMD_DATA_RSP, f->seq, (const uint8_t *)&rsp, sizeof(rsp));
}

static void handle_end(const dfu_frame_t *f)
{
	end_req_t req;
	uint32_t final_crc32;

	if (s_state != DFU_STATE_RECEIVING) {
		send_generic_status_rsp(DFU_CMD_END, f->seq, DFU_STATUS_INVALID_STATE);
		return;
	}
	if (f->len != sizeof(end_req_t)) {
		send_generic_status_rsp(DFU_CMD_END, f->seq, DFU_STATUS_INVALID_ARG);
		return;
	}

	memcpy(&req, f->payload, sizeof(req));

	s_state = DFU_STATE_VERIFYING;

	final_crc32 = dfu_crc32_finalize(s_crc_running);

	if (!s_image_header_seen) {
		s_state = DFU_STATE_ERROR;
		s_last_error = DFU_STATUS_IMAGE_INVALID;
		send_generic_status_rsp(DFU_CMD_END, f->seq, DFU_STATUS_IMAGE_INVALID);
		return;
	}
	if (req.final_size != s_bytes_received || req.final_size != s_expected_size) {
		s_state = DFU_STATE_ERROR;
		s_last_error = DFU_STATUS_INVALID_ARG;
		send_generic_status_rsp(DFU_CMD_END, f->seq, DFU_STATUS_INVALID_ARG);
		return;
	}
	if (req.final_crc32 != final_crc32 || req.final_crc32 != s_expected_crc32) {
		s_state = DFU_STATE_ERROR;
		s_last_error = DFU_STATUS_FINAL_CRC_MISM;
		send_generic_status_rsp(DFU_CMD_END, f->seq, DFU_STATUS_FINAL_CRC_MISM);
		return;
	}
	if (erase_partition_full(s_storage_part) != ESP_OK) {
		s_state = DFU_STATE_ERROR;
		s_last_error = DFU_STATUS_PARTITION_ERROR;
		send_generic_status_rsp(DFU_CMD_END, f->seq, DFU_STATUS_PARTITION_ERROR);
		return;
	}
	if (esp_ota_set_boot_partition(s_main_app_part) != ESP_OK) {
		s_state = DFU_STATE_ERROR;
		s_last_error = DFU_STATUS_IMAGE_INVALID;
		send_generic_status_rsp(DFU_CMD_END, f->seq, DFU_STATUS_IMAGE_INVALID);
		return;
	}

	s_state = DFU_STATE_COMMITTED;
	s_last_error = DFU_STATUS_OK;
	send_generic_status_rsp(DFU_CMD_END, f->seq, DFU_STATUS_OK);
}

static void handle_status(const dfu_frame_t *f)
{
	status_rsp_t rsp = {
		.state = s_state,
		.reserved0 = 0,
		.last_error = s_last_error,
		.bytes_received = s_bytes_received,
		.expected_size = s_expected_size,
	};
	dfu_send_frame(DFU_CMD_STATUS_RSP, f->seq, (const uint8_t *)&rsp, sizeof(rsp));
}

static void handle_abort(const dfu_frame_t *f)
{
	/* Reset sequence so fresh host sessions can start from seq=0 after ABORT. */
	s_expected_seq = 0;
	reset_session();
	s_state = DFU_STATE_IDLE;
	s_last_error = DFU_STATUS_ABORT_DONE;
	send_generic_status_rsp(DFU_CMD_ABORT, f->seq, DFU_STATUS_ABORT_DONE);
}

static void handle_reboot(const dfu_frame_t *f)
{
	esp_err_t err;

	if (f->len > 1) {
		send_generic_status_rsp(DFU_CMD_REBOOT, f->seq, DFU_STATUS_INVALID_ARG);
		return;
	}

	if (f->len == 1) {
		if (f->payload[0] == DFU_TARGET_MAIN_APP) {
			if (s_main_app_part == NULL) {
				send_generic_status_rsp(DFU_CMD_REBOOT, f->seq, DFU_STATUS_PARTITION_ERROR);
				return;
			}
			err = esp_ota_set_boot_partition(s_main_app_part);
			if (err != ESP_OK) {
				send_generic_status_rsp(DFU_CMD_REBOOT, f->seq, DFU_STATUS_PARTITION_ERROR);
				return;
			}
		} else if (f->payload[0] == DFU_TARGET_DFU_APP) {
			if (s_dfu_part == NULL) {
				send_generic_status_rsp(DFU_CMD_REBOOT, f->seq, DFU_STATUS_PARTITION_ERROR);
				return;
			}
			err = esp_ota_set_boot_partition(s_dfu_part);
			if (err != ESP_OK) {
				send_generic_status_rsp(DFU_CMD_REBOOT, f->seq, DFU_STATUS_PARTITION_ERROR);
				return;
			}
		} else {
			send_generic_status_rsp(DFU_CMD_REBOOT, f->seq, DFU_STATUS_UNSUP_TARGET);
			return;
		}
	}

	s_last_error = DFU_STATUS_OK;
	send_generic_status_rsp(DFU_CMD_REBOOT, f->seq, DFU_STATUS_OK);
	vTaskDelay(pdMS_TO_TICKS(100));
	esp_restart();
}
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
void app_main(void)
{
	esp_err_t err;

	esp_log_level_set("*", ESP_LOG_WARN);

	dfu_init_wdt();
	ESP_ERROR_CHECK(dfu_init_partitions());
	ESP_ERROR_CHECK(dfu_init_uart());
	ESP_ERROR_CHECK(dfu_init_status_led());

	reset_session();
	s_state = DFU_STATE_IDLE;
	s_last_error = DFU_STATUS_OK;
	s_expected_seq = 0;
	s_last_activity_us = esp_timer_get_time();
	s_last_heartbeat_us = 0;

	ESP_LOGW(TAG, "DFU booted on UART1 TX=GPIO3 RX=GPIO4, status NeoPixel GPIO21");

	while (true) {
		status_led_service();
		dfu_heartbeat_log_service();
		err = dfu_recv_frame(&s_frame);

		if (err == ESP_ERR_TIMEOUT) {
			if (s_state == DFU_STATE_RECEIVING) {
				int64_t now_us = esp_timer_get_time();
				if ((uint64_t)(now_us - s_last_activity_us) > ((uint64_t)DFU_SESSION_TIMEOUT_MS * 1000ULL)) {
					s_expected_seq = 0;
					reset_session();
					s_state = DFU_STATE_IDLE;
					s_last_error = DFU_STATUS_TIMEOUT;
				}
			}
			esp_task_wdt_reset();
			continue;
		}

		if (err == ESP_ERR_INVALID_CRC) {
			s_last_error = DFU_STATUS_BAD_FRAME_CRC;
			s_state = (s_state == DFU_STATE_RECEIVING) ? DFU_STATE_RECEIVING : s_state;
			esp_task_wdt_reset();
			continue;
		}

		if (err != ESP_OK) {
			s_last_error = DFU_STATUS_INVALID_ARG;
			esp_task_wdt_reset();
			continue;
		}

		s_last_activity_us = esp_timer_get_time();
		process_frame(&s_frame);
		esp_task_wdt_reset();
	}
}

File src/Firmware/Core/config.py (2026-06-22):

import sys

# Detect platform
machine_info = sys.implementation._machine

# Define Pin Dictionary
if "ESP32C3" in machine_info:
    # C3 Configuration
    BOARD = "C3"
    UART_ID = 1
    UART_TX_PIN = 2
    UART_RX_PIN = 3
    I2C_ID = 0
    INA_SCL_PIN = 8
    INA_SDA_PIN = 7
    NEOPIXEL_PIN = 10
    PROBE_PIN = False # unsupported on C3
else:
    # Default to S3 Configuration
    BOARD = "S3"
    UART_ID = 2
    UART_TX_PIN = 3
    UART_RX_PIN = 4
    I2C_ID = 1
    INA_SCL_PIN = 9
    INA_SDA_PIN = 8
    NEOPIXEL_PIN = 21
    PROBE_PIN = 10

# Common constants
SHUNT_RESISTOR_OHMS = 0.003
MAX_EXPECTED_CURRENT_AMPS = 20
INA226_I2C_ADDRESS = 0x40
ledcolor_normalmode = "cyan"
ledcolor_probemode = "magenta"

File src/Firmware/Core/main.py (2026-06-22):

from machine import Pin, UART, I2C
import neopixel
import time, struct
import ina226
import config
import gc
import machine

FIRMWARE_NAME="OPSUM Core Firmware"
VERSION = "0.1"
TARGET_BOARD_REV = "A"
FIRMWARE_STRING = f"{FIRMWARE_NAME},{VERSION},{TARGET_BOARD_REV},{config.BOARD}"

# Named color mapping
NAMED_COLORS = {
    "red": (255, 0, 0),
    "green": (0, 255, 0),
    "blue": (0, 0, 255),
    "yellow": (255, 255, 0),
    "magenta": (255, 0, 255),
    "cyan": (0, 255, 255),
    "white": (255, 255, 255),
    "pink": (255,20,147),
}

def set_internal_led_color(name=None, brightness=1.0):
    """Set ESP32-S3 onboard led (type "WS2812" on pin ) color using NeoPixel.

    If `name` is provided, set the LED to that named color and return.
    If no name is provided, turn off the LED.
    """
    if name:
        rgb = NAMED_COLORS.get(name.lower())
        if rgb:
            # Apply brightness scaling
            scaled_rgb = tuple(int(c * brightness) for c in rgb)
            # print(f"Setting color '{name}' (brightness: {int(brightness * 100)}%): RGB{scaled_rgb}")
            led[0] = scaled_rgb
            led.write()
        else:
            print(f"Color name '{name}' not found.")
        return

    # Turn off LED
    led[0] = (0, 0, 0)
    led.write()


def poll_uart_commands():
    global script_running
    if not uart.any():
        return

    data = uart.read()
    if data is None:
        return

    if b"STATUS" in data:
        uart.write(f"\r\nOK_RUNNING,{FIRMWARE_STRING}\r\n")

    elif b"ENTERDFU" in data:
        # Enter DFU app by selecting the dedicated OTA app partition in otadata.
        try:
            import esp32

            dfu_parts = []
            try:
                dfu_parts = esp32.Partition.find(label="dfu")
            except Exception:
                dfu_parts = []

            if not dfu_parts:
                uart.write("\r\nERR_DFU_PARTITION_NOT_FOUND\r\n")
                return

            dfu_parts[0].set_boot()
            uart.write("\r\nOK_REBOOTING_INTO_DFU_MODE\r\n")
            time.sleep_ms(120)
            machine.reset()
        except Exception as exc:
            print(f"ENTERDFU failed: {exc}")
            uart.write("\r\nERR_DFU_BOOT_TARGET_SET_FAILED\r\n")

    elif b"STOP" in data:
        if script_running:
            uart.write("\r\nOK_STOPPING_MAIN_LOOP\r\n")
            script_running = False

# initialize NeoPixel LED, PROBE+ pin, UART, and I2C
led = neopixel.NeoPixel(Pin(config.NEOPIXEL_PIN), 1)
probe = Pin(config.PROBE_PIN, Pin.IN, Pin.PULL_UP) if config.PROBE_PIN else None
uart = UART(config.UART_ID, baudrate=115200, tx=Pin(config.UART_TX_PIN), rx=Pin(config.UART_RX_PIN))
i2c = I2C(config.I2C_ID, scl=Pin(config.INA_SCL_PIN), sda=Pin(config.INA_SDA_PIN))

# Initialize INA226 sensor over I2C
ina = ina226.INA226(i2c, addr=config.INA226_I2C_ADDRESS)
ina.configure(
    # avg=ina226.INA226.AVG_512, # default
    # avg=ina226.INA226.AVG_16, # faster response
    avg=ina226.INA226.AVG_1, # fastest response (no averaging in firmware, leave that to software side)
    vbusct=ina226.INA226.VBUSCT_588US,
    vshct=ina226.INA226.VSHCT_588US,
    mode=ina226.INA226.MODE_SHUNT_BUS_CONTINUOUS,
)
ina.calibrate(r_shunt_ohms=config.SHUNT_RESISTOR_OHMS, max_expected_amps=config.MAX_EXPECTED_CURRENT_AMPS)

# main loop
ledfadeout = False
script_running = True
try:
    while script_running:
        poll_uart_commands()

        #* Pack data as binary with 2-byte start marker, seq and checksum
        #* Frame layout (little-endian):
        #* - 2 bytes: start marker 0xAA 0x55 (sent as uint16 0x55AA little-endian)
        #* - 1 byte : event type (0x73)
        #* - 1 byte : seq (0..255)
        #* - 4 bytes: timestamp (uint32)
        #* - 4 bytes: bus voltage (float32)
        #* - 4 bytes: current (float32)
        #* - 4 bytes: shunt voltage (float32)
        #* - 4 bytes: power (float32)
        #* - 1 byte : checksum (XOR over bytes from event..power)
        #* - 2 bytes: end marker 0x66 0xBB (sent as uint16 0x66BB little-endian)
        #* Total: 27 bytes
        try:
            if 'seq' not in globals():
                seq = 0
        except Exception:
            seq = 0
        # build payload (event, seq, timestamp, voltage, current, shunt voltage, power)
        ev = 0x73
        ts = int(time.ticks_ms()) & 0xFFFFFFFF
        payload = struct.pack('<BBIffff', ev, seq, ts, ina.bus_voltage, ina.current, ina.shunt_voltage, ina.power)
        # compute simple XOR checksum over payload (event..power)
        checksum = 0
        for b in payload:
            checksum ^= b
        # define start and end markers
        start = struct.pack('<H', 0x55AA)
        end = struct.pack('<H', 0x66BB)
        # construct full frame (start marker + payload + checksum + end marker)
        frame = start + payload + struct.pack('<B', checksum) + end
        try:
            uart.write(frame)
        except Exception:
            # best-effort: try writing in two parts
            try:
                uart.write(start + payload + struct.pack('<B', checksum))
                uart.write(end)
            except Exception:
                pass
        # advance sequence number
        seq = (seq + 1) & 0xFF
        if seq == 0 or seq == 128:
            ledfadeout = not ledfadeout
        if ledfadeout:
            ledbrightness = 1 - (seq / 255)
        else:
            ledbrightness = seq / 255
        if probe and not probe.value():
            ledcolor = config.ledcolor_probemode
        else:
            ledcolor = config.ledcolor_normalmode
        set_internal_led_color(ledcolor, brightness=ledbrightness) # vary brightness with sequence number for visual feedback
        time.sleep_ms(10)
        #print(f"[{config.BOARD}] Sent frame: event={ev}, seq={seq}, ts={ts}, voltage={ina.bus_voltage:.6f}V, current={ina.current:.6f}A, shunt={ina.shunt_voltage:.6f}V, power={ina.power:.6f}W")
except KeyboardInterrupt:
    pass
finally:
    # This block executes when the loop finishes or if the code crashes
    set_internal_led_color() # Ensure LED is turned off on exit

    # Flush the lines completely
    time.sleep_ms(100)
    while uart.any():
        uart.read()
        
    # Tell MicroPython to link this UART to the system REPL (running on UART0)
    # to allow accessing it over the same USB port after the script exits
    import os
    os.dupterm(uart, 0)

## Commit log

2026-06-22 - add JLCPCB step-by-step guide for PCB manufacture and assembly - mention I2C display pin header
2026-07-09 misc improvements: - improve STEP file (correct hole size to fit 3mm acrylic led guides) - add PlatformIO post-build hook for continuous build of updated full firmware binary image - corrected the fu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
    [OPSUM_Enclosure_v1.1.step, OPSUM_Enclosure_v1.step]
2026-07-15 add step-by-step final assembly guide
2026-07-15 simplify assembly steps
2026-07-15 add PCB pad soldering image

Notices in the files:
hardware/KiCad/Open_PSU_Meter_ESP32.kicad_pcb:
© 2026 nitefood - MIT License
